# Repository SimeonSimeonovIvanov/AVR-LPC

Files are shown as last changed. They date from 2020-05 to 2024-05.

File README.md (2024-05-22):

# myPLC

Ladder IDE, Win32 API:<br>
https://photos.app.goo.gl/ECsNng8fbLdXbFrD6<br>

**IDE v6**
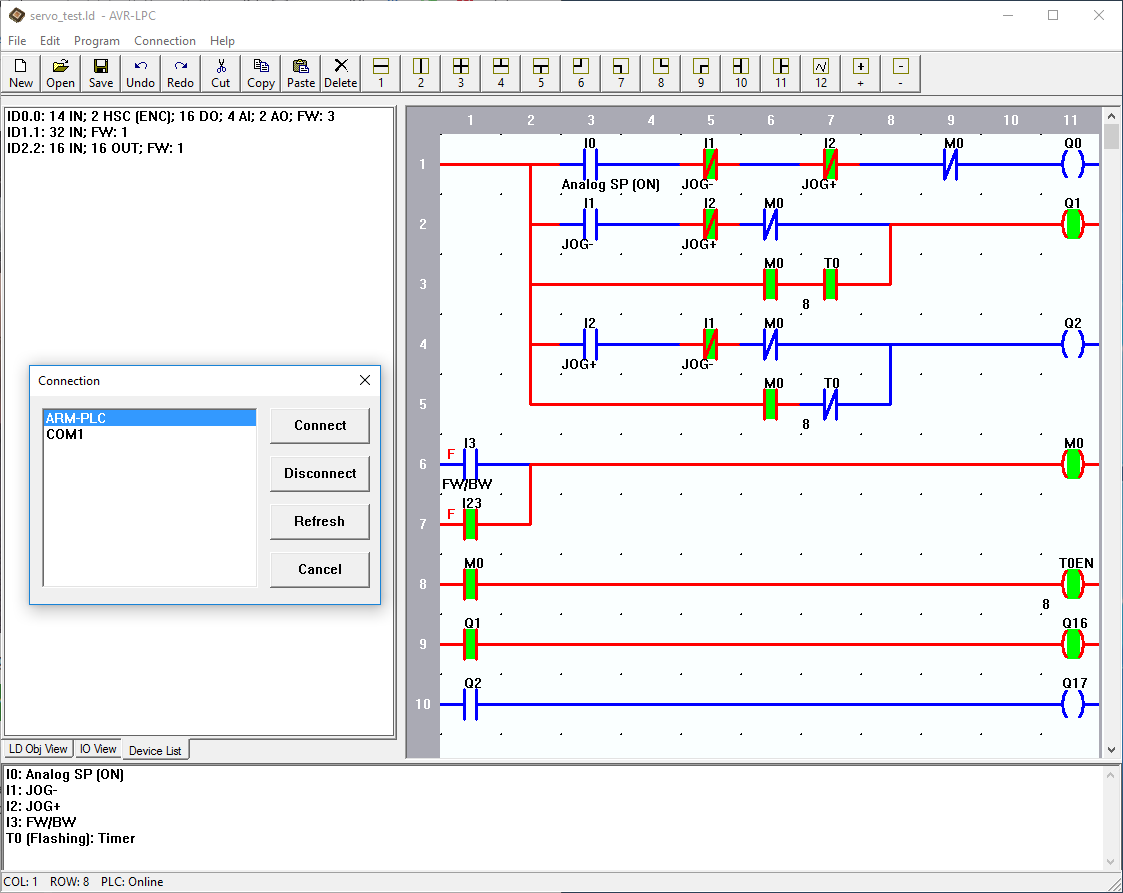
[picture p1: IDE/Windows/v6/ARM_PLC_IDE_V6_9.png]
<br>

**IDE v5**
![Screen Shot](https://lh3.googleusercontent.com/i4vTtbMWcvufEfyPBXmEqtodp0uiaY80SN7nO53SizIuQGnKfskF3hOMWklSdp-E9tZwQFcahZGzqjpb_negQXEel_Ek9y2Q-xKqGe8nZFe8iSiKAYTuJJ7f9EiFlDz4nAf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)<br>

DOS IDE:<br>
<br>

--------------------------------------------------------------------------------------------------------------------------------
**Hardware:**

Electrical Panel: https://photos.app.goo.gl/Vyq1tTFqbRWLNgmy7

1) ARM-PLC v.0.0.0: https://photos.app.goo.gl/mvdGAAyFvAadtSrAA<br>
STM32F446; 14 DI; 1 ENC (2xDI); 16 DO;  4 AI; 2 AO; 1 CAN ( isolated ); 1 RS485 ( isolated ); HMI: LED and SPI expander

![Screen Shot](https://lh3.googleusercontent.com/FQr5hSMQqp2i_nwhZKglB-SCWpj6r-qX7r7Q-jVdQKx1wFxZURQ0LDfvRpwgbzK7AezVR70dovUALOiyYdSaQdRBpPOx6JCb9xz4_ndkZiJmi8XbgmQ-WjyfjlQAHrFRKiS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)

2) v.0.0.9: https://photos.app.goo.gl/yJJbBFp53oGfpSQh1<br>
ATmega128; 16 DI ( isolated ); 16 DO ( isolated ); RS485 ( isolated ); HMI: LED and SPI expander

![Screen Shot](https://lh3.googleusercontent.com/kVyHbxGsG4IzdlXVnGyCS1j1SPNN2gSp2w5qG455mBflZe69VZ90f4dho-pRgDI4RW-WO7sNSD0PA6l9do6jwlTGMlJhjrFqmtGLVl0L7OKdVmlS1hUvMp5UErSR4JhdYPI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)<br>

3) v.0.1.0: https://photos.app.goo.gl/6iC17XjzNHSULanWA<br>
ATmega128; 32 DI ( isolated ); RS485 ( isolated ); HMI: LED and SPI expander

![Screen Shot](https://lh3.googleusercontent.com/OzEl-yrtWVlj1PB5MuoKFS6b4SZ66YS6gCqzX56oWE0lESGWPlYt3V_fz-cltTzUgdABo3lM2OgTONHgAs62rUD7gYELFHMJWC5DPY2WDuDx00NfmaOz2tmeLVn8EhmkOAx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)<br>

4) v.0.0.8 - https://photos.app.goo.gl/Z9C2jXlDd0mY3kmC3 / v.0.0.7 - https://photos.app.goo.gl/mJN1KLpo3TUd7HVa7
ATmega128 + 64KB SRAM; Embedded JTAG ( isolated ); 10 DI ( isolated ); 12 DO ( isolated ); 7 AIN ( 12/16 bits - isolated ); 2 AO ( 16 bits - isolated ); RS485; USB->Virtual Serial Port ( isolated )

![Screen Shot](https://lh3.googleusercontent.com/MFSm0rBE19Bkr6n2bQHMvwQDbrM88FVj6mi0oa1zPS12Zd1XVF8ZQhruDUSjj5ge2i3OTbsoyuJ5pJxQHAq7EGBXzrQ4npnA8TN-FYfQfRKF62vvIBu4lyrC2G8nLSsmaur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)<br>

5) v.0.0.5: https://goo.gl/photos/QCfDXFoU9WnBnyi77
ATxmega128; 10 DI ( isolated ); 12 DO ( isolated ); 7 AI ( not isolated ); 2 AO ( not isolated )

![Screen Shot](https://lh3.googleusercontent.com/CrdKOV2Exipbm48BkSPXY6QQhLZtKpu2Nv74_5UNym-NVNAPvjKg5PgMn0AcWso0ZyiwsN57_bQ84GkdWwb7Ry0Kp0wBErN_FqKzjVGy-RkI7oBeXEOX3lbk3L_sag4jpUt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)<br>

6) v.0.0.3: https://goo.gl/photos/ECHeer7ifiq2STHZ8 - Automatic Fish Feeder With PLC ( old PLC board )
https://www.youtube.com/watch?v=zcFjG9XD-4E&list=PLE616v1yP136VSTElJPbgqLRKw9dhneZ0

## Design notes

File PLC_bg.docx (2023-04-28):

Ladder Editor for ARM PLC v6:

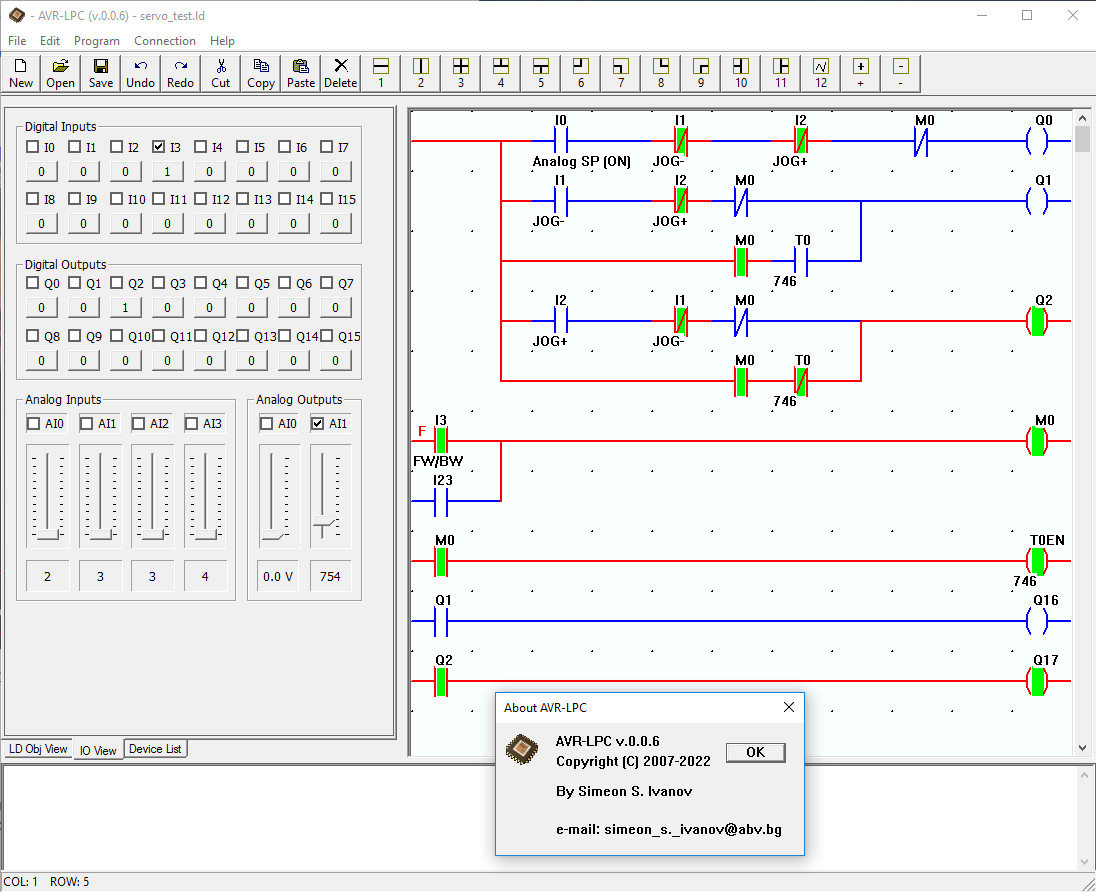
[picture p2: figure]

Ladder Editor for AVR/ARM PLC v5:

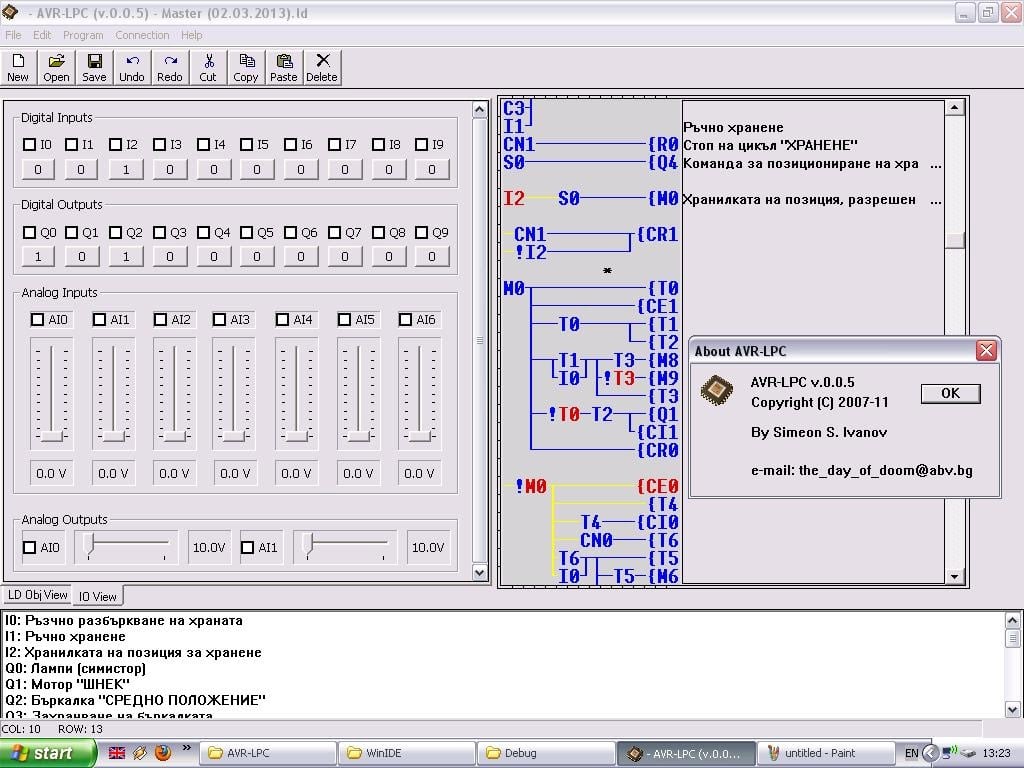
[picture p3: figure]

DOS Version:

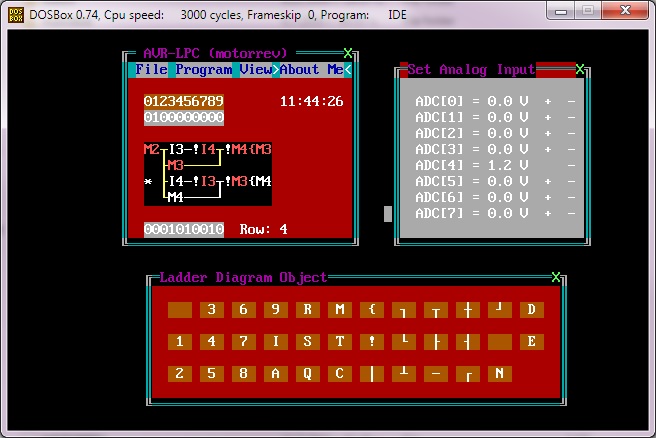
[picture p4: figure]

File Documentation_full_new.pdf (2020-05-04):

# ModBUS âõîäíî-èçõîäåí ìîäóë

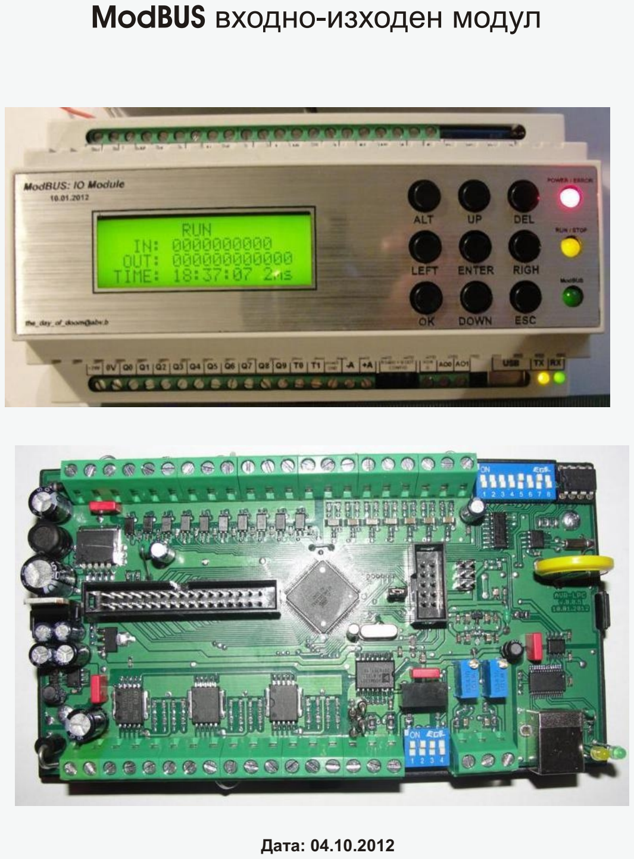
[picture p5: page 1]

## Äàòà: 04.10.2012

### УВОД

Предлаганият | входно/изходен | модул | е | предназначен | за | целите | на
автоматизацията. Управлението му по ModBUS го прави привлекателен за специалистите използващи операторски панели тип PLC, като тяхно входно/изходно разширение. Модулът е базиран на FreeModBUS – open source проект,чийто автор е
Christian Walter MSe. Повече информация може да се намери на www.freemodbus.org.
Приложеното CD съдържа и модифицирания вариант на стека за Atxmega128А1. На него може да бъде видяна и библиотеката на графичния диспплей JM12232

## (SED1520). Източникът и е: http://en.radzio.dxp.pl/sed1520/. Целият останал код, е

авторски и не подлежи на разпространение.

### ОБЩО ОПИСАНИЕ НА МОДУЛА

Модулът е с потребителски интерфейс съставен от LCD дисплей и клавиатура. Кутията е с размери (150x85x85 mm), за монтаж на DIN45 шина.

На фиг.1 е показан общ изглед на модула, разположение на цифровите входове (I0-I9), аналоговите входове (AI0-AI6), цифровите изходи (Q0-Q11), аналоговите изходи (AO0 и AO1), RS485 интерфейса (–A и +A). В Таблица 1 е описано предназначението на ключетата SW1 и SW2, в Таблица 2 – на светодиодите.

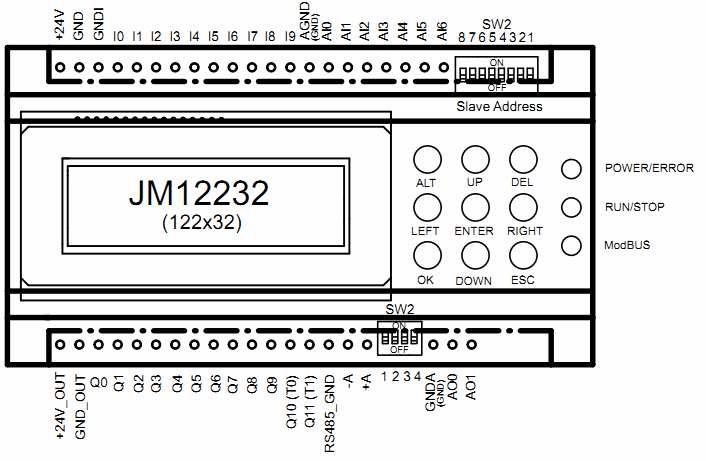
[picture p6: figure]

Таблица 1: Описание на DIP ключетата на модула

Пин | SW1 (номерация отляво надясно в нарастващ ред) | Пин | SW2 (номерация отдясно наляво в нарастващ ред)
1 Включва 120Ω терминиращ | резистор на RS485 интерфейса. | 1 Ако ключе 4 на SW1 e в OFF то след | рестарт SW2 задава адрес на модула в

Фиг.1. Общ изглед на модула

2

3

Включват изтеглящи резистори към RS485 линията.

=//=

4

След рестарт, ако ключето е в OFF не се предприема никакво действие.
В случаите, в които всички ключета на SW2 са в OFF се активира boot loader. Излиза се чрез рестарт или инструкция от програмиращия софтуер.
След излизане от boot loader, при все още активиран ключ BOOT се възстановяват фабричните настройки на модула.

ВАЖНО!!!
Boot loader е опция – в случей че не е добавен, то ключето служи за възстановяване фабричните
настройки на модула.

8

мрежата. Адресът се задава в бинарен вид, като номерата на битовете вървят отдясно-наляво в нарастващ ред.
Ако адресът е невалиден се изписва съответното съобщение, очаквайки въвеждане на коректен адрес и потвърждаване чрез OK. За модулите без UI – чрез рестарт.

Таблица 2: Описание на статусните светодиоди на модула

| СВЕТЕЩ | УГАСНАЛ | МИГАЩ (0.5Hz) | БЪРЗО МИГАЩ
POWER/ERROR | Захранен модул | N/A | Засечена грешка | N/A
RUN/STOP | Модулът е в STOP | N/A | Модулът е в RUN | N/A
ModBUS | N/A | Очакване на пакет | Изтекъл time out на комуникацията, модулът е в “STOP – Time Out” режим | Приемане/Предаване на пакети по ModBUS, модула може да е в RUN или STOP режим.

Комуникацията с PLC се осъществява чрез галванично развързан RS485 интерфейс или виртуален сериен порт, през USB, удобен за връзка с персонален компютър при липса на конвертор за RS485. Разполага с 10 цифрови входа и 12 цифрови изхода (24VDC, оптично развързани. Застъпена е и аналоговата част: 7 входа
и 2 изхода (0-10VDC).

Аналоговите входове позволяват директно прочитане на измерената стойност или преобразуваната в диапазона: от 0 до 100 единици с дискрета 0.1V или от 0 до 1000 съответно през 0.01V. Точността на канал е ±2%.

Аналоговите изходи стандартно се управляват с дискрета от 0.1V (от 0 до 100 единици за 10V обхват). Възможно е дирекно задаване на стойност (0 – 4095) или чрез дискрета от 0.01V. Изборът на работен режим на аналоговата част се осъществява чрез команди по ModBUS. Точността на канал е ±2%.

ТЕХНИЧЕСКИ ХАРАКТЕРИСТИКИ

Параметър | Минимална стойност | Номинална стойност | Максимална стойност | Измервателна единица
Захранване на модула | 18.0 | 24.0 | 36.0 | V, DC
| + | 130.0 | 150.0 | mA
Температура на околната среда | 0.0 | 27.0 | 40.0 | °C
Цифрови входове: 10 опто изолирани | Работно напрежение (абсолютни максимуми) | -40.0 | 0.0 – 24.0 | +40.0 | V, DC
| Логическа ‘1’ | 15.0 | 24.0 | 40.0
| Логическа ‘0’ | -40.0 | 0.0 | 10.0
| Пробивно напрежение между входовете и масата на модула | + | + | 100.0 | V, DC/AC
| Работен ток | 1.0 | 3.0 | 5.0 | mA
| Време за реакция | Основно се определя се от комуникацията по ModBUS | | | ms.
| | + | 50.0 | +
Цифрови Изходи: 12 опто изолирани | Захранване | 20.0 | 24.0 | 36.0 | V, DC
| Пробивно напрежение между изходите и масата на модула | + | + | 100.0 | V, DC/AC
| Изходен ток на канал, защита от късо на изхода. | + | 500.0 | Термична защита при късо на изхода | mA
| Сумарен ток на всички канали | + | + | 6.0А | A
| Време за реакция | Основно се определя се от комуникацията по ModBUS | | | ms.
| | + | 100.0 | +
Аналогови входове: 7 без изолация | Входно напрежение | -30.0 | 0.0 ÷ 10.0 | +30.0 | V, DC
| Входно съпроти-вление на канал | Входното съпротивление се определя от операционен усилвател свързан като повторител, по желание на потребителя на платката може да се добави паралелен входен резистор със стойност от 10kΩ за измерване на напрежение или нискоомен 400Ω (2x200Ω; R0805) за преобразуване на входен ток до 25 mA в номиналното напрежение на входа. Ако се ползва стандартния високоомен вход, при липса на сигнал, модулът ще отчете входно напрежение около 11V (напрежението на насищане на ОУ).

| | >> 100.0 -- | kΩ
Отклонение от измерваната стойност | + | ±10.0 | ±20.0 | mV
Резолюция – за максимална точност се препоръчва директен достъп до регистрите и последващо преобразува не. | 0.1 0.1 | | 0.01 или директен прочит на работните им регистри | V, DC
Време за реакция | Основно се определя се от комуникацията по ModBUS | | | ms.
| + | 100.0 | +
| Изходно напрежение, липсва защита от обратно напрежение | ~0.005 | 0.005 ÷ 10.0 | ~10.70 | V, DC
| Грешка от отместване | ±5.0 | ±10.0 | ±20.0 | mV
| Резолюция | 0.1 | 0.1 | 0.01 или директен запис на работните им регистри | V, DC
| Изходен ток, защитиа от късо | + | 10.0 | ~40.0 | mA
| Време за реакция | Определя се от комуникацията по ModBUS | | | ms.
| | + | 100.0 | +

Аналогови
изходи:

### 2 без

изолация

### ВНИМАНИЕ!!!

1) Параметрите на модула са ориентировачни. Всички са свалени при стайна температура.
2) За калибриране на аналоговите входове и изходи е ползван мултицет MASTECH
MS8218.

### НАСТРОЙКА НА МОДУЛА ЧРЕЗ ПОТРБИТЕЛСКИЯ ИНТЕРФЕЙС (UI)

В нормален работен режим се извежда статус дисплей. На него се изобразява състоянието на модула (спрян/пуснат), грешки, входовете и изходите. Чрез еднократно натискане на ALT могат да се видят измерените стойности на аналоговите входове. При повторно натискане се показват и зададените стойности на аналоговите изходи. Аналоговите изходи се изобразяват в текущия диапазон: 0.0-10.0V; 0.01-10.00V или директно стойността записана в работните регистри. Натискането на ESC ни връща в статусния прозорец.

Навигацията и задаването на параметри се осъществява чрез бутоните на клавиатурата:
UP/ DOWN – Преместване на курсора, задаване на нова стойност на параметър LEFT/ RIGHT – Преместване на курсора, задаване на нова стойност на параметър ENTER – Влизане в подменю
ESC – Връщане стъпка назад, без промяна на последното задание
OK – Избор на текуща стйност на параметър.

Статус дисплей->OK->Главно меню->ENTER->Status:
ОК->Run – Привежда изходите (цифрови и аналогови) в работно състояние ОК->Stop - Привежда изходите (цифрови и аналогови) в не работно състояние (стойности 0)
ESK – връщане в главното меню, без промяна на последното задание

## Статус дисплей->OK->Главно меню->Time Config->ENTER:

ALT / LEFT – задават се часовете
UP / ENTER – задават се минутите
DEL / RIGHT – задават се секундите
OK – възприемане на новите настройки
ESK – връщане в главното меню, без промяна на последното задание

## Статус дисплей->OK->Главно меню->ModBUS Config->ENTER:

BAUD Rate->ENTER: Избор между няколко скорости на комуникацията
(OK – Потвърждаване; ESC – меню назад)
Select Port->ENTER: Избор между RS485 или виртуален сериен порт през USB
(OK – Потвърждаване; ESC – меню назад)
Time Out->ENTER: Колко време след спиране на комуникацията контролерът преминава в стоп режим по изтекло време. Повторното стартиране на контролера е възможно едва когато се възтанови комуникацията чрез команда от UI или през
ModBUS.

### ОПИСАНИЕ НА КОМУНИКАЦИОНИЯ ПРОТОКОЛ

Комуникацията с модула се извършва чрез ModBUS. При този протокол комуникацията между устройствата е на базата главен-подчинен(и). Главното

(master) устройство представлява PLC или PC, а модула – подчинено (slave). В нормално състояние всички подчинени устройства очакват заявка от главното.
Заявката | съдържа | адреса | на | устройството, команда | за | четене/запис | на
регистър/регистри, самата информация и CRC.

## MODBUS RTU

ВАЖНО!!! – текущата версия на модула поддържа само “Big Endian” формат на данните. Това означава, че старшите битове се изпращат преди младшите.

Физически слой:

Атрибут | Описание
Интерфейс | RS485, Виртуален сериен порт (USB<>COM). Избират се чрез UI на модула или чрез ModBUS запис в регистър.
Информационен формат | ”Big Endian” 1 стоп бит 8 дата бита Контрол по четност (Even Bit) 2 стоп бита
Стандартни скорости | 19200, 38400, 57600 и 115000 bps. Избират се чрез UI на модула или чрез ModBUS запис в регистър (при втория вариант могат да бъдат зададени и други скорости на комуникация).

### ФОРМАТ НА MODBUS RTU ПАКЕТ

Пакетът, изпращан от master към slave и обратно представлява:

## ID_Slave, Function_Code, User_Data, CRC16

ID_Slave – Идентификатор на slave device, цяло число, в диапазона от 1 до 247. Нула е специален адрес: ползва се за едновременно подаване на заявка към всички устройства в мрежата.

Function_Code – Оределя регистровата област върху която ще се чете и/или записва. Пряко е обвързана с формата на User_Data.

User_Data – Информацията която се изпраща към модула. Формата й се определя от Function_Code, в общия случай съдържа стартов адрес и брой регистри. Ако командата е запис се включва и новото съдържание на регистрите.

CRC16 – Чек сума на пакета.

При валидно изпратен и master, slave връща отговор съдържащ номера му, използвания функционален код, потребителската информация (ехо при запис) или евентуален код за грешка.

### КОМАНДИ (ФУНКЦИОНАЛНИ КОДОВЕ) ПОДЪРЖАНИ ОТ МОДУЛА

Функционалните кодове определят контекста и формата на съобщението. Те непосредствено определят върху коя група от регистри се изпълнява текущата команда:

Офицялни Команди подържани от модула

Код | Група | Описание

Регистрите представляват масиви от битове*, байтове или думи разпределени по групи според разрешените действия върху тях (четене и/или запис).

Битовите регистри на модула са пряко обвързани с входовете и изходите му включително и някои вътрешни състояния. Те реално са логическа структура. Достъпът до тях се осъществява чрез командите за работа с байтови регистри, съставени от желаните битове.

### ЧЕТЕНЕ НА ДИСКРЕТНИ ВХОДОВЕ (FC2)

Заявка от Master:

Байт | Описание
0 | Адрес на подчиненото устройство (1 – 247), 0 е за адресиране на всички устройства
1 | Функционален код 0x02
2 | Адрес на първия бит (MSB)
3 | Адрес на първия бит (LSB)
4 | Брой на битовете за четене (MSB)
5 | Брой на битовете за четене (LSB)
6 | CRC16 LSB
7 | CRC16 MSB

Отговор от Slave:

Байт | Описание
0 | Адрес на отговарящото подчинено устройство
1 | Функционален код 0x02
2 | Брой върнати байтове
3 | Байт 0
N | Байт N
3 + Брой баитове | CRC16 LSB
4 + Брой байтове | CRC16 MSB

Примерна команда за прочитане на 16-те бита:

## 10, 2, 0, 0, 0, 16, CRC[120,189] Device ID: 10

FC: 2

## Start Address: 0 Bits count: 16 (2 Byte)

Разпределението на битовете във върнатите байтове е: BYTE[0] - Цифрови входове:

(FC)
2 Еднобайтови регистри само за четене | (разделени логически на отделни битове). | Четене на дискретни входове
1 Четене на дискретни изходи 5 Запис на един дискретен изход | Еднобайтови регистри за четене/запис: Coils (разделени логически на отделни битове).
15 | | Запис на няколко дискретни изхода

4 16 битови регистри само за четене
3 Четене на 16 битови регистри 6 Запис на 16 битов регистър | 16 битови регистри за четене/запис.
16 | Запис на 16 битови регистри

## BIT[0:7] - Входове [I0:I7]

BYTE[1] - Цифрови входове:

## BIT[0:1] - Входове [I8:I9]

BIT 2 - Защита на изходите (1 – Задействана защита)

BIT[3:7] – Не се ползват

ЧЕТЕНЕ НА ДИСКРЕТНИ ИЗХОДИ (FC1)

Заявка от Master:

Байт | Описание
0 | Адрес на подчиненото устройство (1 – 247), 0 е за адресиране на всички устройства
1 | Функционален код 0x01
2 | Адрес на първия бит (MSB)
3 | Адрес на първия бит (LSB)
4 | Брой на битовете за четене (MSB)
5 | Брой на битовете за четене (LSB)
6 | CRC16 LSB
7 | CRC16 MSB

Отговор от Slave:

Байт | Описание
0 | Адрес на отговарящото подчинено устройство
1 | Функционален код 0x01
2 | Брой върнати байтове N
3 | Байт 0
N Байт N
3 + N | CRC16 LSB
4 + N | CRC16 MSB

Примерна команда за прочитане на 16-те бита:

## 10, 1, 0, 0, 0, 16, CRC[60,189] Device ID: 10

FC: 1

## Start Address: 0 Bits count: 16 (2 Byte)

Разпределението на битовете във върнатите байтове е:

BYTE[0] - Цифрови изходи:

## BIT[0:7] - Изходи [Q0:Q7]

BYTE[1] - Цифрови изходи:

## BIT[0:1] - Изходи [Q8:Q9] BIT[2:3] – Изходи [Q10:Q11] <=>[T0:T1]

BIT[4:7] – Не се ползват

### ЗАПИС НА ДИСКРЕТЕН ИЗХОД (FC5)

Заявка от Master:

Байт Описание

0 | Адрес на подчиненото устройство (1 – 247), 0 е за адресиране на всички устройства
1 | Функционален код 0x05
2 | Адрес на изходния бит (MSB)
3 | Адрес на изходния бит (LSB)
4 | Стойност на Бита(Изхода): 0xff – Битът се вдига в единица; 0x00 – Битът се смъква в нула
5 | 0x00
6 | CRC16 LSB
7 | CRC16 MSB

Отговор от Slave:

Байт | Описание
0 | Адрес на отговарящото подчинено устройство
1 | Функционален код 0x05
2 | Адрес на изходния бит (MSB)
3 | Адрес на изходния бит (LSB)
4 | Стойност на Бита(Изхода): 0xff – Битът e единица; 0x00 – Битът e нула
5 | 0x00
6 | CRC16 LSB
7 | CRC16 MSB

Примерна команда за запис на единица в нулевия изход (Q0):

## 10, 5, 0, 0, 255, 0, CRC[141,65] Device ID: 10

FC: 5

## Start Address: 0 Coil (Q0) state: 1 (0xff)

### ЗАПИС НА ДИСКРЕТНИ ИЗХОДИ (FC15)

Заявка от Master:

Байт | Описание
0 | Адрес на подчиненото устройство (1 – 247), 0 е за адресиране на всички устройства
1 | Функционален код 0x015
2 | Адрес на изходния бит (MSB)
3 | Адрес на изходния бит (LSB)
4 | Брой битове (MSB)
5 | Брой битове (LSB)
6 | Брой байтове N
N + 6 | Битова маска 0
N + 7 | Битова маска N
N + 8 | 0x00
N + 9 | CRC16 LSB
N + 10 | CRC16 MSB

Отговор от Slave:

Байт | Описание
0 | Адрес на отговарящото подчинено устройство
1 | Функционален код 0x015
2 | Адрес на изходния бит (MSB)
3 | Адрес на изходния бит (LSB)
4 | Брой битове (MSB)
5 | Брой битове (LSB)

5 + Брой баитове | CRC16 LSB
6 + Брой байтове | CRC16 MSB

Примерна команда за запис на единици на първите осем изхода (Q0 – Q7):

## 10, 15, 0, 0, 0, 8, 1, 255, CRC[255, 102] Device ID: 10

FC: 15

## Start Address: 0 Coil Count: 8 Byte Count: 1 Coil Mask: 255 (0xff)

### ЧЕТЕНЕ НА 16 БИТОВИ ВХОДНИ РЕГИСТРИ (FC4)

Заявка от Master:

Байт | Описание
0 | Адрес на подчиненото устройство (1 – 247), 0 е за адресиране на всички устройства
1 | Функционален код 0x04
2 | Адрес на първия регистър (MSB)
3 | Адрес на първия регистър (LSB)
4 | Брой регистри за четене (MSB)
5 | Брой регистри за четене (LSB)
6 | CRC16 LSB
7 | CRC16 MSB

Отговор от Slave:

Байт | Описание
0 | Адрес на отговарящото подчинено устройство
1 | Функционален код 0x04
2 | Брой върнати байтове N (2 x Брой регистри за четене)
3 | WORD[0] (MSB)
4 | WORD[0] (LSB)
N + 1 | WORD[N-1] (MSB)
N + 2 | WORD[N-1] (LSB)
3 + Брой баитове | CRC16 LSB
4 + Брой байтове | CRC16 MSB

Примерна команда за директно прочитане на 7-те аналогови входа без корекция:

## 10, 4, 0, 0, 0, 7, CRC[176, 179] Device ID: 10

FC: 4

## Start Address: 0 Word count: 7 (14 Byte)

Разпределението на регистрите във върнатите байтове е: WORD_0[BYTE_0:BYTE_1] – Аналогов вход 0, директен прочит

WORD_1[BYTE_2:BYTE_3] – Аналогов вход 1, директен прочит
=//=

## WORD_6[BYTE_12:BYTE_13] – Аналогов вход 6, директен прочит

### ЧЕТЕНЕ НА 16 БИТОВИ ВХОДНО/ИЗХОДЕНИ РЕГИСТРИ (FC3)

Заявка от Master:

Байт | Описание
0 | Адрес на подчиненото устройство (1 – 247), 0 е за адресиране на всички устройства
1 | Функционален код 0x03
2 | Адрес на първия регистър (MSB)
3 | Адрес на първия регистър (LSB)
4 | Брой регистри за четене N (MSB)
5 | Брой регистри за четене N (LSB)
6 | CRC16 LSB
7 | CRC16 MSB

Отговор от Slave:

Байт | Описание
0 | Адрес на отговарящото подчинено устройство
1 | Функционален код 0x03
2 | Брой върнати регистри N
3 | WORD[0] (MSB)
4 | WORD[0] (LSB)
N + 1 | WORD[N-1] (MSB)
N + 2 | WORD[N-1] (LSB)
3 + Брой баитове | CRC16 LSB
4 + Брой байтове | CRC16 MSB

Примерна команда за прочитане на коригиращите константи на 7-те аналогови входа:

## 10,3,0,5,0,7, CRC[21,114] Device ID: 10

FC: 3

## Start Address: 5 Word count: 7 (14 Byte)

Разпределението на регистрите във върнатите байтове е: WORD_5[BYTE_10:BYTE_11] – Калибрираща константа на Аналогов вход 0

WORD_6[BYTE_12:BYTE_13] – Калибрираща константа на Аналогов вход 1
=//=
WORD_11[BYTE_22:BYTE_23] – Калибрираща константа на Аналогов вход 6

### ЗАПИС НА 16 БИТОВ ВХОДНО / ИЗХОДЕН РЕГИСТЪР (FC6)

Заявка от Master:

Байт | Описание
0 | Адрес на подчиненото устройство (1 – 247), 0 е за адресиране на всички устройства
1 | Функционален код 0x06
2 | Адрес на регистъра (MSB)
3 | Адрес на регистъра (LSB)

4 | Нова стойност на регистъра: WORD[0] (MSB)
5 | Нова стойност на регистъра: WORD[0] (LSB)
6 | CRC16 LSB
7 | CRC16 MSB

Отговор от Slave:

Байт | Описание
0 | Адрес на отговарящото подчинено устройство
1 | Функционален код 0x06
2 | Адрес на регистъра (MSB)
3 | Адрес на регистъра (LSB)
4 | Върната информация: WORD[0] (MSB)
5 | Върната информация: WORD[0] (LSB)
6 | CRC16 LSB
7 | CRC16 MSB
Примерна команда за запис на RUN в статусната дума на модула и изчистване на последно възникналите грешки:

## 10,6,0,15, OLD_STATUS>>8, ~0x03 & OLD_STATUS, CRC Device ID: 10

FC: 6

## Start Address: 15

ЗАПИС НА 16 БИТОВИ ВХОДНО / ИЗХОДНИ РЕГИСТРИ (FC16)

Заявка от Master:

Байт | Описание
0 | Адрес на подчиненото устройство (1 – 247), 0 е за адресиране на всички устройства
1 | Функционален код 0x10
2 | Адрес на първия регистър (MSB)
3 | Адрес на първия регистър (LSB)
4 | Брой 16-битови регистри за запис N (MSB)
5 | Брой 16-битови регистри за запис N (LSB)
6 | Брой 8-битови регистри за запис (2 * N)
7 | WORD[0] (MSB)
8 | WORD[0] (LSB)
N + 7 | WORD[N-1] (MSB)
N + 8 | WORD[N-1] (LSB)
6 | CRC16 LSB
7 | CRC16 MSB

Отговор от Slave:

Байт | Описание
0 | Адрес на отговарящото подчинено устройство
1 | Функционален код 0x10
2 | Брой върнати регистри N
3 | WORD[0] (MSB)
4 | WORD[0] (LSB)
N + 1 | WORD[N-1] (MSB)
N + 2 | WORD[N-1] (LSB)
3 + Брой баитове | CRC16 LSB
4 + Брой байтове | CRC16 MSB

Примерна команда за нулиране на калибриращите константи на аналоговите изходи (не се препоръчва ако не се познава достатъчно добре модулът и начините за възстановяване на константите му по ModBUS):

## 10, 16, 0, 12, 0, 2, 4, 0, 0, 0, 0,CRC[214,222] Device ID: 10

FC: 16

## Start Address: 5 Word count: 2 (4 Byte)

### РЕГИСТРОВА КАРТА НА МОДУЛА

Регистри за четене / запис (8-битови организирани в 16 адресируеми бита), FC1,

## FC5 и FC15:

Байт, Начален адрес | Бит | Предназначение | Стойност
1 | 0
0 | 0 Цифров изход Q0 | | Задействан | Не задействан
| =//= | =//=
| 7 Цифров изход Q7
1 | 0 Цифров изход Q8
| =//= | =//=
| 7 Цифров изход Q15
2 | 0 Цифров изход Q16
| =//= | =//=
| 7 Цифров изход Q23

Регистри само за четене (16-битови), FC4:

WORD начален адрес | Байт | Предназначение | Стойност ,
MSB | LSB | | Минимална | Максимална
0 | 1 | 0 | Аналогов вход AI0, стойност прочетена от ADC-то | 0 | Определя се от константата на аналоговия вход
=//= | =//= | =//= | =//=
6 | 13 | 12 | Аналогов вход AI6, стойност прочетена от ADC-то
7 | 15 | 14 | Аналогов вход AI0, скалирана стойност | 0 | 1000

Регистри само за четене (8-битови организирани в 16 адресируеми бита), FC2:
Байт, начален адрес | Бит | Предназначение | Стойност
1 | 0
0 | 0 Цифров вход I0 | | Задействан | Не задействан
| =//= | =//=
| 7 Цифров вход I7
1 | 0 Цифров вход I8
| =//= | =//=
| 7 Цифров вход I15
2 | 0 Цифров вход I16
| =//= | =//=
| 7 Цифров вход I23
3 | 0 Термична защита на изходите
| =//= | N/A
| 7 N/A

=//= | =//= | =//= | =//= | Отговаря на 0.00 V | Отговаря на 10.00 V
13 | 27 | 26 | Аналогов вход AI6, скалирана стойност
14 | 29 | 28 | Аналогов вход AI1 | Аналогов вход AI0 | 0 Отговаря на 0.0 V | 100 Отговаря на 10.0 V
15 | 31 | 30 | Аналогов вход AI3 | Аналогов вход AI2
14 | 33 | 32 | Аналогов вход AI5 | Аналогов вход AI4
16 | 35 | 34 | N/A | Аналогов вход AI6

Регистри за четене и запис (16-битови), FC3, FC6 и FC16:

WORD начален адрес | Байт | Предназначение | Стойност ,
MSB | LSB | | Минимална | Максимална
0 | 1 | 0 | Аналогов изход AO0, стойност без корекция | 0 | Определя се на базата константата на аналоговия изход
1 | 3 | 2 | Аналогов изход AO1, стойност без корекция
2 | 5 | 4 | Аналогов изход AO0, скалирана стойност | 0 Отговаря на 0.00 V | 1000 Отговаря на 10.00 V
3 | 7 | 6 | Аналогов изход AO1, скалирана стойност
4 | 9 | 8 | Аналогов изход AO1 | Аналогов изход AO0 | 0 Отговаря на 0.0 V | 100 Отговаря на 10.0 V
5 | 11 | 10 | Калибрираща константа на аналогов вход AI0 | | 0 | 20470 (стойност на аналоговия вход умножена по десет, при 10.00V задание)
=//= | =//= | =//= | =//=
11 | 23 | 22 | Калибрираща константа на аналогов вход AI6
12 | 25 | 24 | Калибрираща константа на аналогов изход AO0
13 | 27 | 26 | Калибрираща константа на аналогов изход AO1
| Байт | Бит | Стойност | Значение
| 28 LSB, Аналогови входове | [0..1] | 0 Без промяна на предишното състояние
| | | 1 Пълен диапазон: 0 ÷ 2047 – НЕ СЕ ПОЛЗВА!
| | | 2 Диапазон: 0 ÷ 1000 (0.00 V - 10.00 V) – НЕ СЕ | ПОЛЗВА!
| | | 3 Диапазон: 0 – 100 (0.0 V - 10.0 V) – НЕ СЕ ПОЛЗВА!
| | 2 | 1/0 | N/A
| | 3 | 1/0 | N/A
| | 4 | 1/0 | N/A
| | 5 Зареждане на фабричните калибриращи константи | 1 - Старт 0 – Край (Статус)

### 6 Зареждане на калибриращите константи от

### EEPROM

7 | | Зареждане на калибриращите константи в EEPROM
29 MSB, Аналогови изходи | DAC0 [0..1] и DAC1 [2..3] | 0 Без промяна на предишното състояние
1 Пълен диапазон: 0 ÷ 4095 | | Сменя работния диапазон и формата на изобразяваната информация на екрана на DAC.

### 2 Диапазон: 0 ÷ 1000 (0.00 V - 10.00 V)

3 | Диапазон: 0 – 100 (0.0 V - 10.0 V)
4 | 1/0 | Зареждане на работния диапазон в EEPROM
5 | 1 - Старт | Зареждане на фабричните калибриращи константи

14

| | 6 Зареждане на калибриращите константи от | 0 - Край | EEPROM
| | 7 | | Зареждане на калибриращите константи в EEPROM
| 30 LSB, статусни битове, последна грешка | 0 1 – Run | 0 – Stop | Run разрешава извеждането на стойности на цифровите и аналоговите изходи Stop режим привежда изходите в неутрално състояние нула.
| | 1 Термична защита, изчиства се ръчно.
| | 2 1/0 | | Задействана защита (1) по time out на комуникацията. Модулът автоматично минава в stop режим от който се излиза след подаване на команда RUN (ръчно или по ModBUS), при което бита се изчиства до следващия time out.
| | 4 | 1/0 | N/A
| | 5 | 1/0 | N/A
| | 6 | 1/0 | N/A
| | 7 | 1/0 | N/A
| 31 MSB, статусни битове, последна грешка | 0 | 1/0 | N/A
| | 1 | 1/0 | N/A
| | 2 | 1/0 | N/A
| | 3 | 1/0 | N/A
| | 4 | 1/0 | N/A
| | 5 | 1/0 | N/A
| | 6 | 1/0 | N/A
| | 7 | 1/0 | N/A
WORD, начален адрес | Байт | Предназначение | Стойност
MSB | LSB | | Минимална | Максимална
16 | 33 | 32 | BAUD Rate / 10 | 9600/10 bps. | 115000/10 bps.
17 | Байт | Бит | Стойност | Значение
| 34 LSB, Сериен порт, контролен регистър | | 0 Без промяна на предишното състояние
| | | 1 Even

15

### 2 Odd [0..1] 3 None

[2..3] | 0 Без промяна на предишното състояние
| 4 | RS485
| 8 FT232 (USB Serial)
6 | 1/0 | N/A
7 | 1/0 | N/A
35 LSB, Сериен порт, контролен регистър | 0 | 1/0 | N/A
| 1 | 1/0 | N/A
| 2 | 1/0 | N/A
| 3 | 1/0 | N/A
| 4 | 1 | Зареждане на новите настройки
| 5 | 1 | Зареждане на фабричните настройки
| 6 | 1 | Зареждане на настройките от EEPROM
| 7 | 1 | Зареждане на настройките в EEPROM
WORD, начален адрес | Байт | Предназначение | Стойност
MSB | LSB | | Минимална | Максимална
18 | 37 | 36 | ModBUS Time out – Време на изчакване след прекъсване на комуникацията, изтече ли контролера минава в стоп режим по time out. | 100 ms или 0 – Забранява time out | 10,000 ms.

### ОСОБЕНОСТИ ПРИ ПОЛЗВАНЕ НА АНАЛОГОВИТЕ ВХОДОВЕ

При директно четене на измерената стойност от аналогов вход, напрежението се определя по формулата:

,[0.00..10.10] 100 ][,

N,CONST

N | N
AI

## AI V = AI ×

### Където:

AIN,CONST е цяло число, със стойност от 10000 до 20470. Средно варира около 18000 (1.8V). Физически се определя от резисторен делител, смъкващ напрежението до 2.048V (максимално). Константите на входовете могат да се променят, зареждат, записват в /от EEPROM или да се възстановят заводските им стойности.

### ОСОБЕНОСТИ ПРИ ПОЛЗВАНЕ НА АНАЛОГОВИТЕ ИЗХОДИ

За да се определи константата, трябва аналоговият изход да е в режим директно извеждане на стойност. В този случай се зарежда максималната му стойност 4095. Измерва се полученото напрежение и се пресмята по формулата:

_ | [, ]
4095 100 ( | ), | Измерено Напрежение V
A | CONST N
OUT | = | ×

Полученото цяло число е в диапазона от 30000 до 40950. Физически се определя от коефицента на усилване и изходния диференциален усилвател.

Константите на изходите могат да се променят, зареждат, записват в / от EEPROM или да се възстановят заводските им стойности.

### НАСТРОЙКИ НА КОМУНИКАЦИЯТА ПО MODBUS

Командата за потвърждаване на новите настройки на серийния порт трябва да се извършва не по-често от 500 mS, в противен случай е възможно ModBUS стека да блокира.

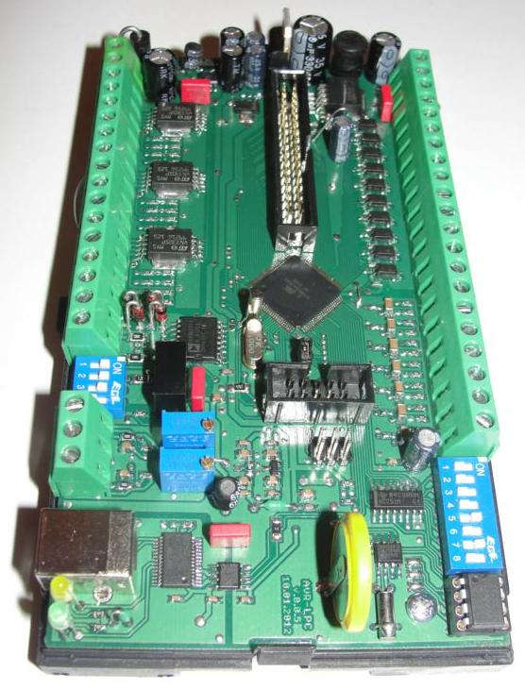
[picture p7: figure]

## ModBUS входно-изходен модул

## Board and Software: v.0.0.5

## (работна документация)

***
***
***

## Дата: 04.10.2012

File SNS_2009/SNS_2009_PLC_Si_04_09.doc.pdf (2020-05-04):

РУСЕНСКИ УНИВЕРСИТЕТ | СТУДЕНТСКА НАУЧНА СЕСИЯ – СНС’09

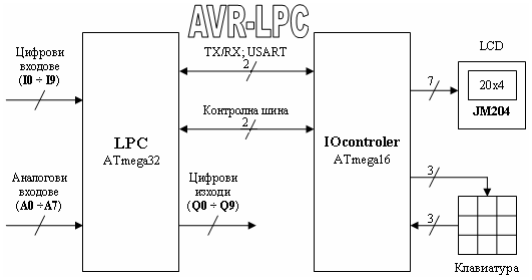
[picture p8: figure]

Програмируем контролер AVR–LPC

автор: Симеон Иванов
научен ръководител: гл. ас. д-р инж. Анелия Манукова

Целта на статията е да представи проект “AVR-PLC”, изграждащ PLC контролер и включващ крайно устройство с интегриран потребителски интерфейс (UI) и ядро (kernel), грижещо се за изпълнение на ladder diagram. Представена е развойна среда, ускоряваща процеса на разработване и тестване на потребителските програми.
Ключови думи: PLC, ladder diagrams, IDE, x86, DOS

ВЪВЕДЕНИЕ
При съвременното развитие на електронните устройства за управление на технологични обекти и процеси широко приложение намират програмируемите логически контролери (PLC). Тяхна основна цел е изместването на управляващите устройства, изградени на релейно-контакторна база. За разлика от хардуерните решения, при които логиката е „твърдо” зададена, при PLC е софтуерно (програмно), позволявайки гъвкавост при изготвянето и настройването на системата. Съществуват множество езици и методи за програмиране, като в настоящия проект са избрани ladder diagrams (стълбични диаграми), които се явяват пряк заместител на релейно-контакторна схемотехника.

ИЗГРАЖДАНЕ НА ПРОГРАМИРУЕМ ЛОГИЧЕСКИ КОНТРОЛЕР AVR–LPC Структурната схема на AVR–LPC е показана на фиг.1. За реализацията му са използвани микроконтролери на фирмата ATMEL. Представяният PLC контролер е изграден на базата на два осем битови микроконтролера: ATmega32 с 32 КBytes Flash и ATmega16 с 16 КBytes Flash. ATmega32 изпълнява основната част от софтуера: ядрото (kernel), грижещо се за изпълнението на диаграмата, потребителския интерфейс (UI), системния часовник и всички софтуерни обекти (часовници, таймери, броячи и др.). Вторият контролер е входно - изходен (IOcontroler), като за неговата реализация е ползван ATmega16. Обслужва управлението на дисплея (JM204; буквено – цифров; 20х4 символа) и клавиатура (9 бутона). Комуникацията между двата контолера е двупосочна, чрез сериен интерфейс, като допълнително е добавена контролна шина.

Фиг.1. Структурна схема на AVR–LPC.

Алгоритъмът на работа на главния контролер AVR–LPC е показан на фиг.2. Блок „Началното установяване” инициализира системните променливи, IOcontroler, зареждане на ladder diagram и настройките от EEPROM, както и стартиране на системата. Следва оперативният цикъл. Той обработва потребителския интерфейс UI, четат се цифровите входове, изпълнява се потребителската програма и получения резултат се записва на цифровите изходи. Частта от алгоритъма, свързана с пунктир на фиг.2., обработва прекъсванията. От нея ясно се вижда, че системния часовник е с най-висок приоритет, грижейки се за обновяването на часа и обектите на ladder diagram: таймери и часовници. Заявката за прекъсването на ADC прочита и филтрира измерената стойност на аналоговия входа на контролера.

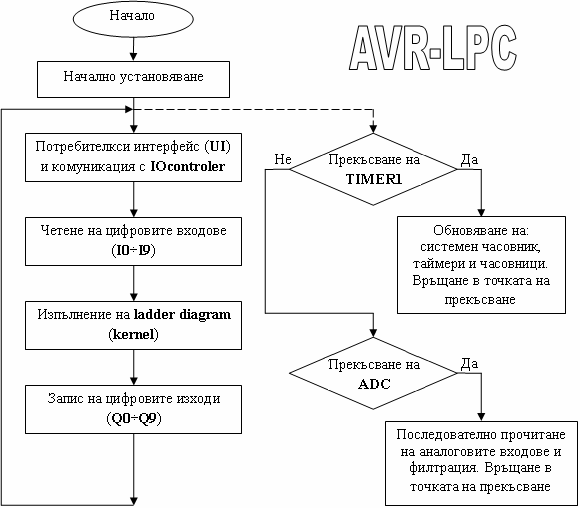
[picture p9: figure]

На фиг.3. е показан алгоритъмът на работа на входно – изходния контролер (IOcontroler). От контекста на фиг.2. се вижда, че LPC контролера е главен, a IOcontroler е подчинен. След началното установяване, следва цикъл на командите. В зависимост от типа на командата, последната се подава на драйвера на дисплея или клавиатурата.
Подсистемата | на | клавиатурата | използва | двупосочната | връзка | между
контролерите (за разлика от тази на дисплея, чакаща заявки за изпълнение). При подаване на команда за прочитане на последния избран бутон, IOcontroler връща ASCII кода му съхранен в буфер. Драйверът на клавиатурата използва заявките за прекъсване, за сканиране и засичане на натиснат бутон.

Фиг.2. Блок-схема на алгоритъма на работа на главния контролер AVR–LPC.

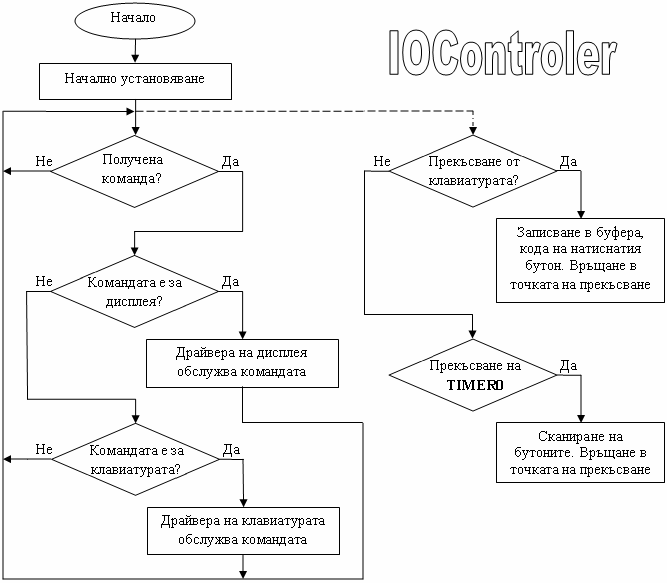
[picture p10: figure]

РЕЗУЛТАТИ
Техническите параметри на изградения AVR-LPC са представени в табл.1. Разделението на хардуерни и софтуерни параметри е наложено от структурата на крайното устройство. Хардуерните описват контролера като черна кутия с n входа и m изхода. Софтуерните показват вътрешната и структура – дават ясна представа за възможностите й. Описаните софтуерни обекти са реализирани по 10 броя.
В табл.1 е зададено „гарантирано време за реакция” като продължителността на оперативния цикъл варира в зависимост от големината и сложността на въведената програма. Измерването му е извършено при размер на диаграмата от 16x12 символа.
При проведените тестове за максимален размер 16х30 символа, ограничен от наличната памет на контролера, се отчете минимален период на оперативния цикъл от порядъка на 25ms. Следователно „гарантираното време за реакция” нараства на 50ms, при запазена резолюция на таймерите и броячите от 1ms. Отчитайки факта, че контролерът е предназначен за управление на инертни процеси, може да се направи извода, че постигнатите резултати във времето са добри.
Въпреки, че спада към micro PLC, от софтуерна гледна точка, ядрото може да подържа до 256 входно – изходни точки и обекта на ladder diagram. Ограниченията произтичат от страна на хардуера.

Фиг.3. Блок-схема на алгоритъма на работа на входно - изходния контролер на
AVR–LPC (IOcontroler).

Таблица.1. Технически параметри на програмируемия контролер AVR–LPC

Успоредно с контролера е разработена развойна среда (IDE), работеща под управлението на операционните системи DOS, Windows 98, Windows NT или Linux (с подходящ емулатор: DOSBox или Wine), като на ниво ядро те са напълно съвместими. DOS приложението е с меню прозоречен интерфейс.
Диалоговият прозорец на DOS средата е показан на фиг.4. Виждат се: зареден фрагмент от суматор, прозорци за редактиране на аналогов компаратор, брояч и диалог за запазване на файл. Главния прозорец, съдържа индикация за състоянието на входовете и изходите, бутони за задаване на стойността на цифровия вход.

Хардуерни параметри
цифрови входове (I0÷I9) | - минимално време за реакция: 10ms; - гарантирано време за реакция: >20ms;
цифрови изходи (Q0÷Q9) | - минимално време за реакция: 10ms; - гарантирано време за реакция: >20ms;
аналогови входове (A0÷A7; мултиплицирани) | - 10-bit ADC; - честота на дискретизация: 125KHz; - софтуерен филтър;

Софтуерни параметри
ladder diagram: 16x12 символа | - произволен формат на запис; - автоматично разпознаване на въвеждания обект;
часовници | - 24 часов период; - час на включване/ изключване;
таймери | - минимален период: 10ms; - гарантиран период: >20ms; - максиален период: 65,535s; - три режима на работа: мултивибратор, таймер със закъснение на включването (ON delay timer), таймер със закъснение на изключването (OFF delay timer);
аналогови компаратори | - софтуерно избиране стойността на опорно напрежение; - тип на сравнение: <; =; >; - избор на аналогов вход;
броячи | - избор посоката на броене (чрез контактна инструкция) - типа на сравнение: <; =; >; - максимална стойност: 65535; - възможност за автоматично нулиране на брояча; - минимално време за реакция: 10ms.; - гарантиранo време за реакция: >20ms;

маркери
RS тригери

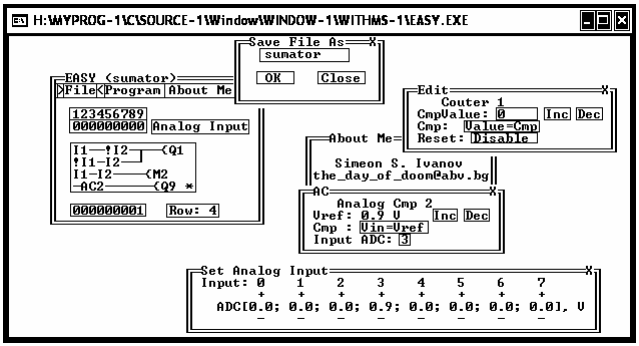
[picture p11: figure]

ЗАКЛЮЧЕНИЕ
Разработен е програмируем логически контролер.AVR-LPC, изпълняващ ladder diagram, и съпъстващатата го развойна среда. При наличие на подходящ хардуер пригоден за работа в промишлени условия (компютър базиран на х86 процесор, например PC/104), приложението може да се ползва директно, спестявайки разработването на специализиран хардуер. Ползването на х86 система, ще осигори по-голям обем и скорост на изпълнение на ladder diagram. В DOS среда, потребителя разполага с файлова система, позволяваща съхраненение, зареждане, изпълнение на произволна програма. Това определя и по-високата продуктивност на предложената система.
Проведените тестове на прототипа и развойната среда на контролера доказват работоспособността му и определят предложената система като гъвкава и надеждна.
Бъдещата работа по контролера е насочена основно върху хардуера, което включва допълнителни модули и осъществяване на връзката им с развойната среда. Предвижда се и добавяне на комуникационен интерфейс за работа в мрежа.

ЛИТЕРАТУРА

### [1] Hugh Jack, Automating Manufacturing Systems with PLCs, http://clay-more.engineer.gvsu.edu/~jackh/books.html [2] Data Sheet, ATmega16/ATmega32, ATMEL

За контакти:
Симеон С. Иванов, студент специалност “Електроника”, 2 курс, Русенски

### университет “Ангел Кънчев”, e-mail: the_day_of_doom@abv.bg

гл. ас. д-р инж. Анелия Владимирова Манукова, кат. “Електроника”, Русенски

### университет “Ангел Кънчев”, тел.: 082 888 366, е-mail: amanukova@ecs.ru.acad.bg

Рецензент:

Фиг.4. Диалогов прозорец на развойната среда.

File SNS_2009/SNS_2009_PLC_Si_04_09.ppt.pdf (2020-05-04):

## СТУДЕНТСКА НАУЧНА КОНФЕРЕНЦИЯ НА РУСЕНСКИ УНИВЕРСИТЕТ „АНГЕЛ КЪНЧЕВ”

2009 г.

## Програмируем контролер AVR–LPC

кат. Електроника при РУ “Ан.Кънчев”

автор: Симеон Иванов

научен ръководител: гл. ас. д-р инж. Анелия Манукова

# ЦЕЛ

Презентацията представя проект “AVR-PLC”,

## изграждащ PLC контролер включващ крайно устройство с интегриран потребителски интерфейс (UI) и ядро (kernel), грижещо се за

изпълнение на ladder diagram.

## Представена е развойна среда, ускоряваща процеса на разработване и тестване на потребителските

програми.

# Структурна схема на AVR–LPC

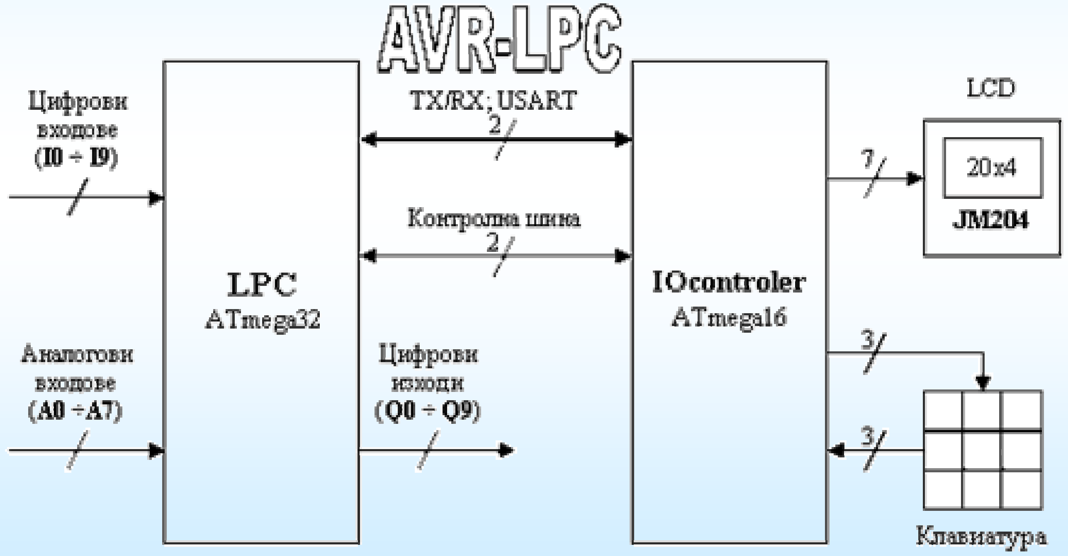
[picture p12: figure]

# Алгоритъм на работа на главния контролер AVR–LPC

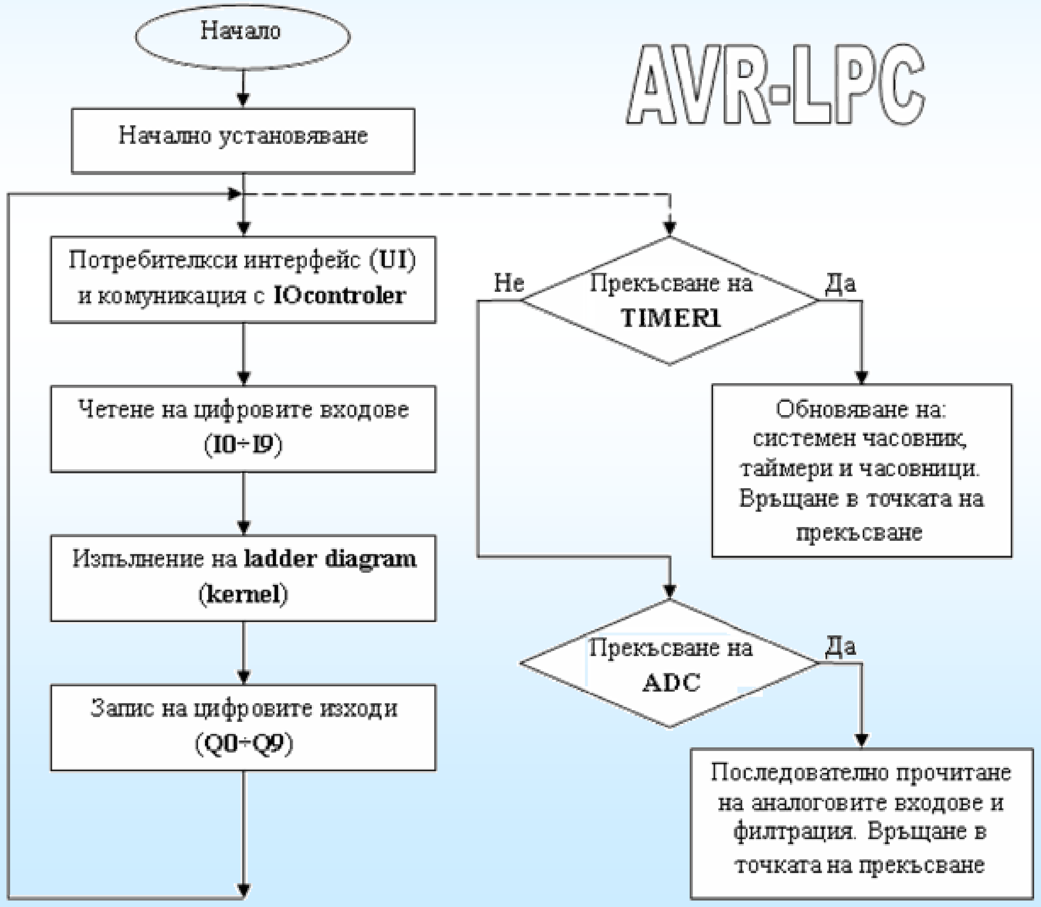
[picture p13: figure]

## Алгоритъм на работа на входно -изходния контролер на AVR–LPC

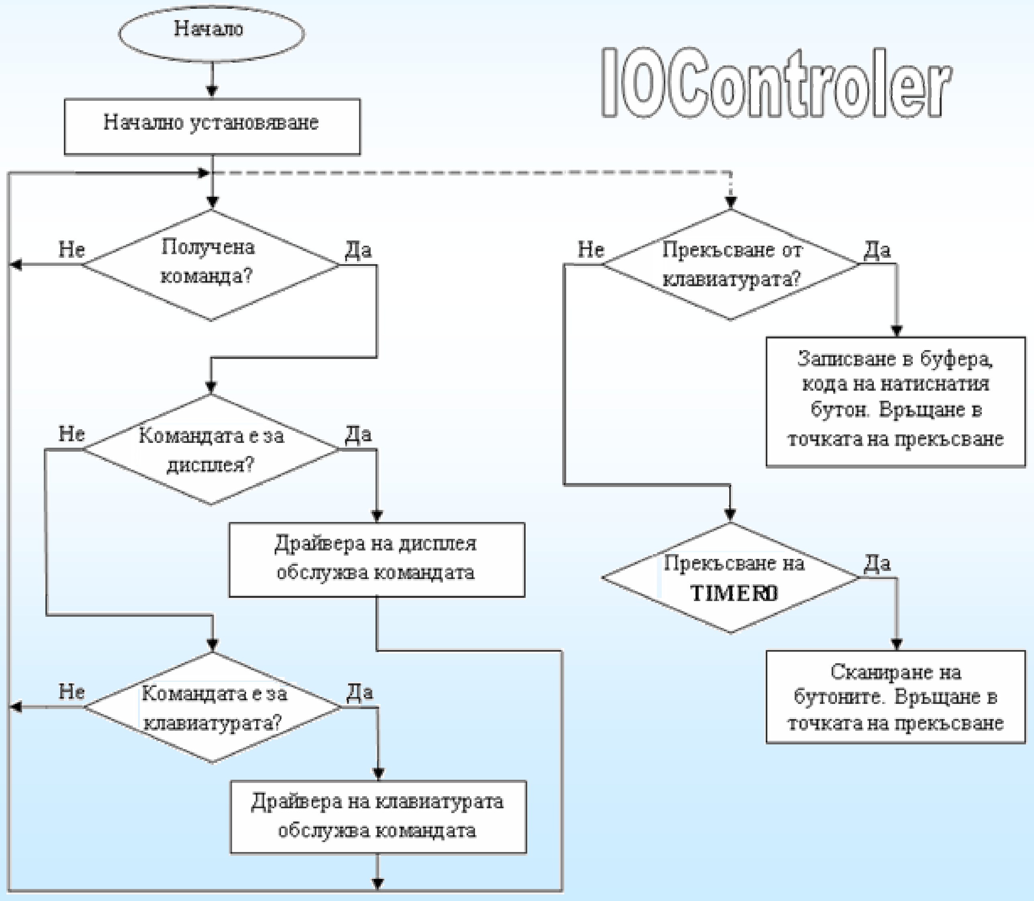
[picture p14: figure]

## Резултати

## Технически параметри на програмируемия контролер AVR–LPC

- 10-bit ADC; - честота на дискретизация: 125KHz; - софтуерен филтър; аналогови входове (A0÷A7; мултиплицирани) | - минимално време за реакция: 10ms; - гарантирано време за реакция: >20ms; цифрови изходи (Q0÷Q9) | - минимално време за реакция: 10ms; - гарантирано време за реакция: >20ms; цифрови входове (I0÷I9)

Хардуерни параметри

- минимален период: 10ms; - гарантиран период: >20ms; - максиален период: 65,535s; - три режима на работа:
мултивибратор, | таймер | със
закъснение на включването (ON delay timer), таймер със закъснение на
изключването (OFF delay timer);

таймери

- 24 часов период; - час на включване/ изключване; часовници | - произволен формат на запис; - автоматично разпознаване на въвеждания обект; ladder diagram: 16x12 символа

Софтуерни параметри

## Резултати

## Технически параметри на програмируемия контролер AVR–LPC

RS тригери

маркери | - избор посоката на броене (чрез контактна инструкция) - типа на сравнение: <; =; >; - максимална стойност: 65535; - възможност за автоматично нулиране на брояча; - минимално време за реакция: 10ms.; - гарантиранo време за реакция: >20ms; броячи | - софтуерно избиране стойността на опорно напрежение; - тип на сравнение: <; =; >; - избор на аналогов вход; аналогови компаратори

## Резултати

## Технически параметри на програмируемия контролер AVR–LPC

## Диалогов прозорец на развойната среда

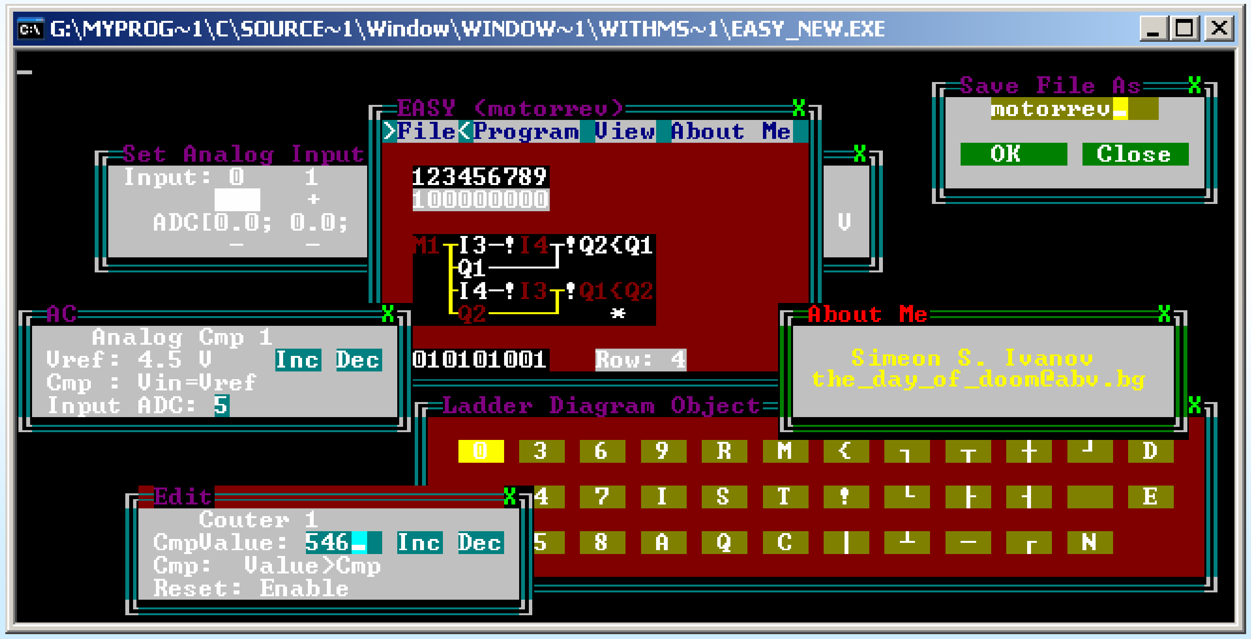
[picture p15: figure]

## ИЗВОДИ

| Разработени са програмируем логически контролер AVR- LPC, изпълняващ ladder diagram, и съпъстващата го развойна среда.
| В DOS среда, потребителя разполага с файлова система, позволяваща съхраненение, зареждане, изпълнение на произволна програма. Това определя и по-високата продуктивност на предложената система.
| Проведените тестове на прототипа и развойната среда на контролера доказват работоспособността му и определят предложената система като гъвкава и надеждна.

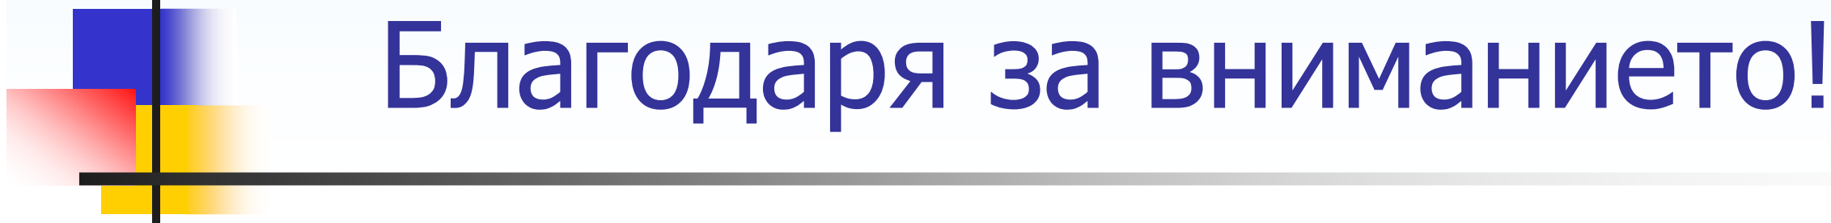
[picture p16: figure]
Благодаря за вниманието!

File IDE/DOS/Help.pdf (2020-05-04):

ИНСТАЛИРАНЕ И КОНФИГУРИРАНЕ

Развойната среда на AVR-LPC (LD.exe) е DOS приложение което може да работи и в среда на емулация в Windows среда. За да може да се използва пълноцено е необходимо да се изпълнят следните правила:

1) Стартиране на развойната среда от файла IDE.exe – конзолна Windows програма иницялизираща драйвера за достъп до входно/ изходните портове, след което подава управлението на LD.exe.
2) Работа на цял екран – режим стартиращ по подразбиране. Необходима е за коректната комуникация между развойната среда и програмирания PLC контролер. За излизане/влизане от него се използва се използва клавишната комбинация ALT+ENTER.
3) Инсталиране на DLPORTIO (драйвер за директен достъп до портовете под Windows NT и производните му).
4) Потребителските програми се съхраняват в работната директория на развойната среда. Желателно е тя да е в корена на диска. Например “C:\LDIDE\” или още по-добре да се ползва диск различен от системния.

При стартиране на IDE.exe, се минава в режим на цял екран. На фиг.1 е показан главния прозорец на редактора.

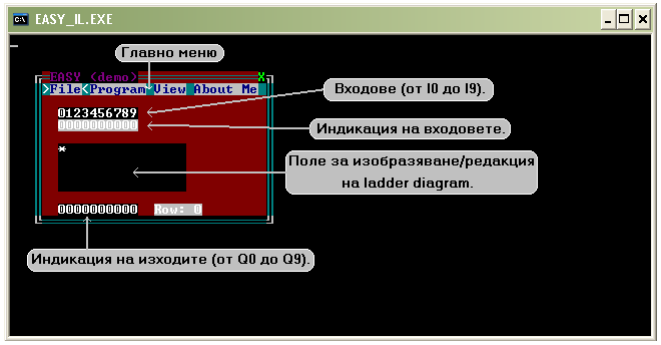
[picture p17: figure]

Фиг.1. Главен прозорец на EASY_IL (IDE)

Съдържа главно меню, бутони (от 0 до 9) имитиращи входовете, непосредствено под тях е съответната им индикация (логическа 0 или 1). Следва полето на LD, а накрая е индикация на изходите.

ГЛАВНО МЕНЮ

Състои се от четири елемента, първите три със съответните им PopUp менюта:

1) File – Предоставя възможност за създаване (New), отваряне (Open), съхранение текущите промени (Save) и запaзване във създаден от потребителя файл (Save as) на Ladder Diagram. Съдържа и полето Exit заизход от редактора. Трябва да се направят три важни уточнения:

а) Избирането на New не съхранява текущата диаграма;

б) При създаване на нова диграма, за да работи Save е необходимо предварително чрез Save as да се зададе име на файла;

в) При избор на Exit се излиза от редактора без съхраняване на последно направените промени;

2) Program – Служи за управление на текущата програма::

а) Compile генерира от текущата ladder diagram файл с разширение *.IL, съдържащ псевдоасмблерни инструкции описващи диаграмата;

б) Run – за разрешаване симулацията на LD;

в) Stop – спира симулацията на LD, запазват се текущите стойности на маркерите, броячите и д.р. обекти на диаграмата;

г) Reset – нулира състоянията и настройките на обектите на LD;

д) Convert – при зареждане на програмен файл от стария формат, се налага конвертиране в текущия. Напрактика опция ползвана само в процеса на разработка.

3) View – за извеждане на два основни прозореца:

а) LD Object – показва и позволява въвеждането на всички символи подържани от LD. Използва се за редакция на диаграмата, навигацията в нея се извършва чрез стрелките (фокуса остава на главния прозорец).;

б) Analog Input – за въвеждане стоийности на аналоговите входове на контролера;

4) About Me – извежда прозорец съсдържащ информация за автора.

Редакция на ladder diagram

За редакция на диаграмата има два основни варианта: чрез прозореца LD Object или от клавиатурата. Втория вариянт позволява вмъкване на специални символи чрез клавишите или ендократно натискане на Enter старртира режим въвеждане на символ (избира се чрез стрелките). Ще бъда разгледани двата варианта.

### РЕДАКЦИЯ ЧРЕЗ „LD Object”

От главното меню се избира View->LD Object. Работния плот придобива следния вид (фиг.2):

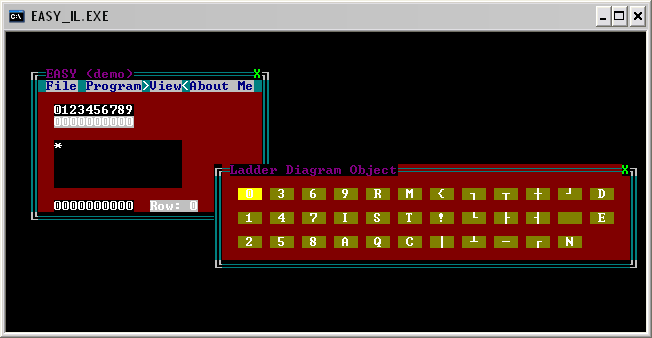
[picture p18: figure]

Избора на елемент става чрез клавиша Tab или мишката, а вмъкването чрез Enter. Стрелките на клавиатурата служат за навигация в полето за редакция на ladder diagram. Чрез SPACE се трие въведения символ.

### РЕДАКЦИЯ ЧРЕЗ КЛАВИАТУРАТА

При редактиране на LD чрез клавиатурата в сила са следните съотвествия между символите изграждащи обектите на ladder diagram и клавишите (таблица 1):

### Таблица 1

### Редакция на ladder diagram чрез “бързите” клавиши

Enter | Режим въвеждане на символ/ Потвърждение на въвеждането.
Space | Изтрива символа маркиран от курсора (звездичка).

Стрелки (наляво, надясно, нагоре, надоло) | За навигация в полето на LD; Избор на елемент в режим на редакция (Enter).
‘-‘ (минус) | ─
‘|’ | │
‘F’ | ┌
‘K’ | ┐
‘G’ | ┴
‘U’ | ┬
‘О’ | ┤
‘V’ | ├
‘B’ | ┘
‘L’ | └
‘X’ | ┼
‘I’, ‘Q’, ‘A’, ‘N’, ‘M’, ‘R’, ‘S’, ‘T’, ‘C’, ‘E’, ‘D’, ‘{‘, ‘0’..’9’, ‘!’ | Съответните им символи.

ВХОДОВЕ
Контролера разполага с десет входа, от I0 до I9. Инвертирането на вход става чрез символа ‘!’.

ИЗХОДИ
Контролера разполага с десет изхода, от Q0 до Q9. Изхода може да се ползва като контактна инструкция или релеен. Когато се използва като контакт инвертирането му става чрез символа ‘!’.

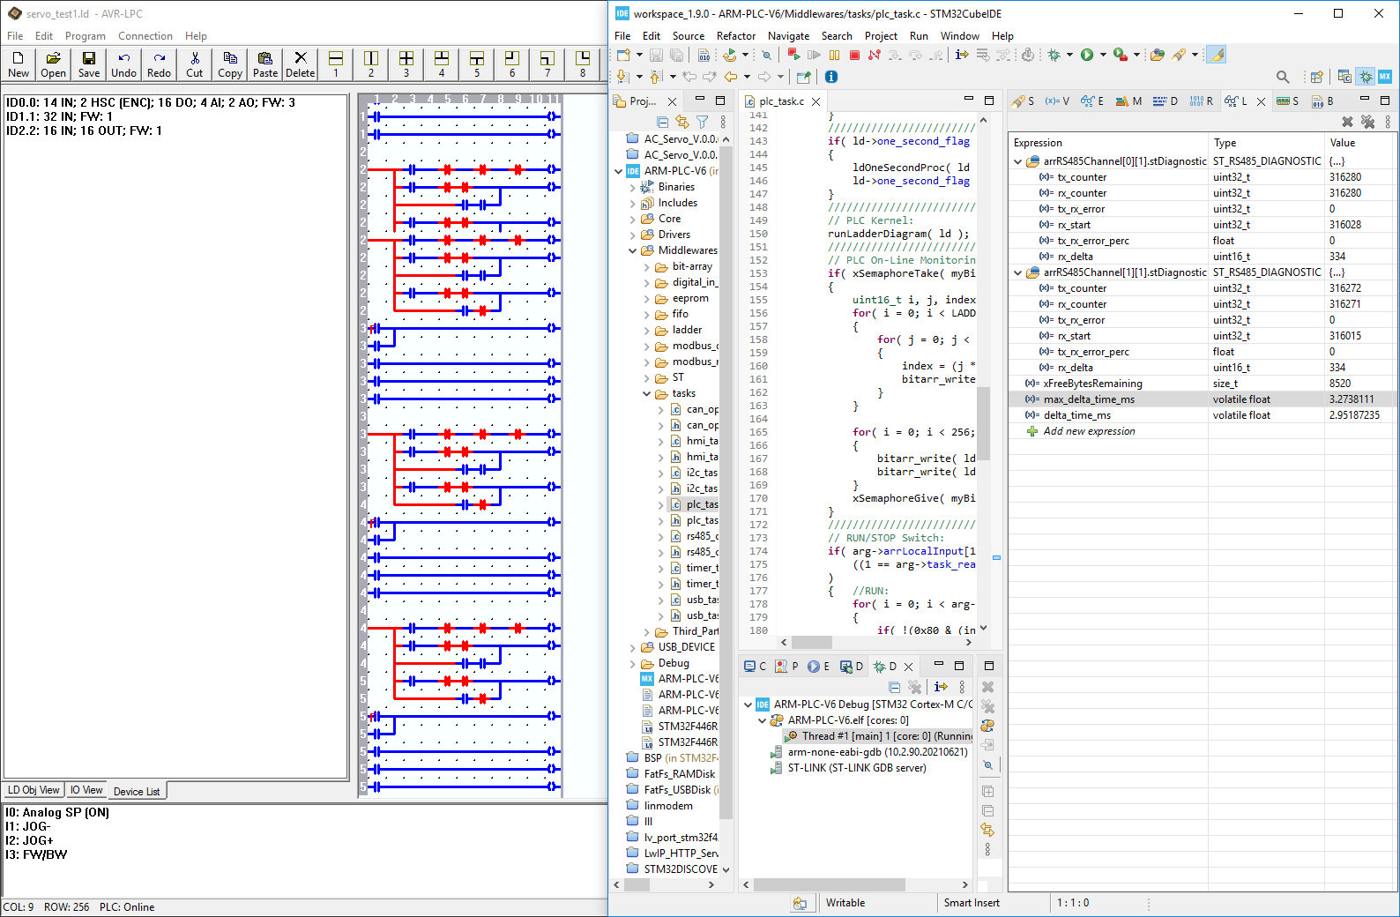
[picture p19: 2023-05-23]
IDE/Windows/v6/ARM_PLC_IDE_V6_8.png

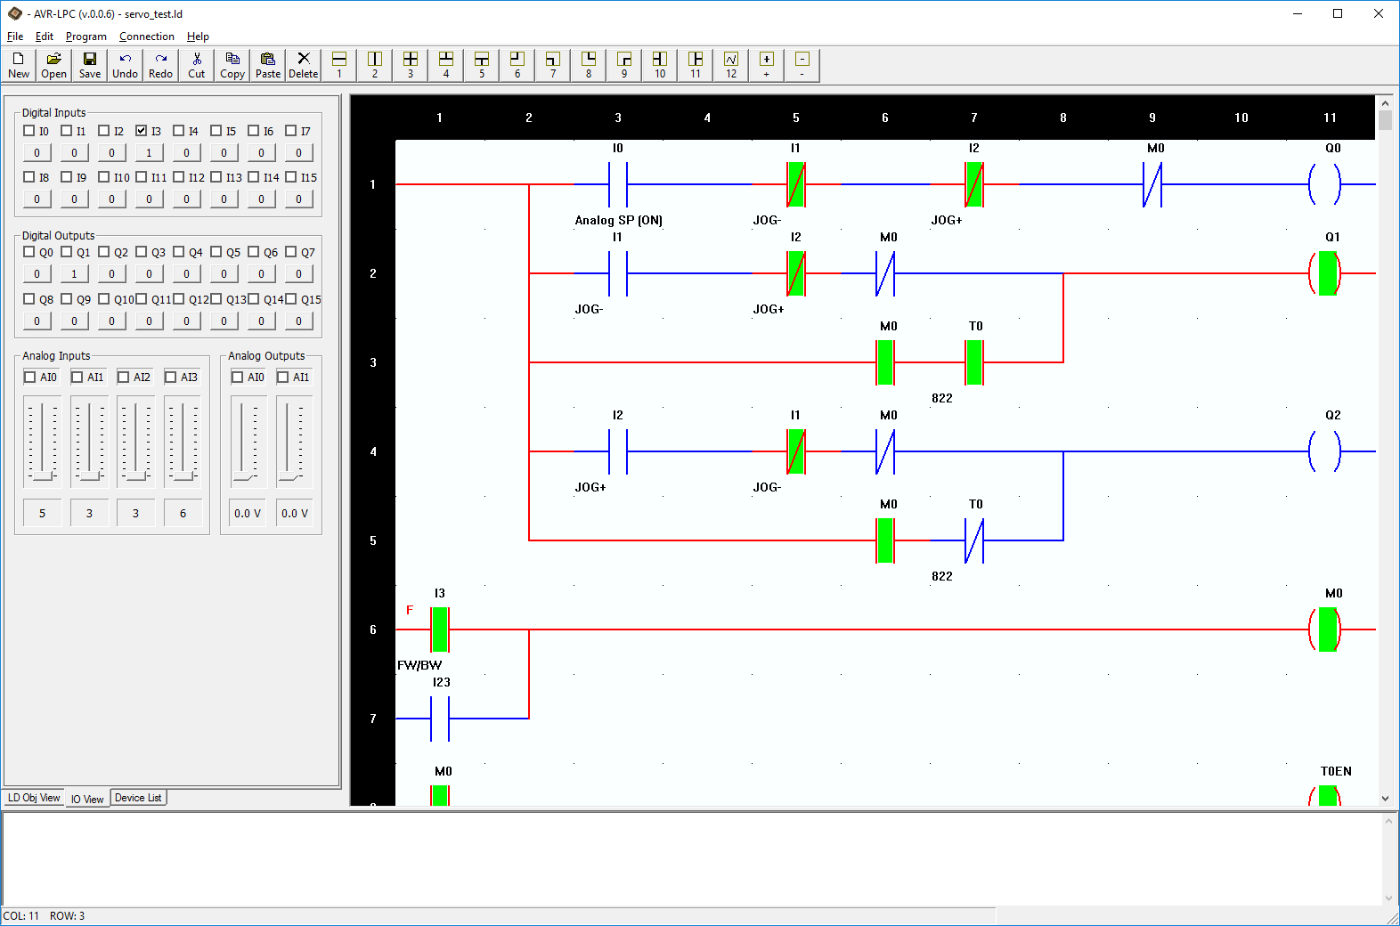
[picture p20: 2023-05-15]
IDE/Windows/v6/ARM_PLC_IDE_V6_6.png

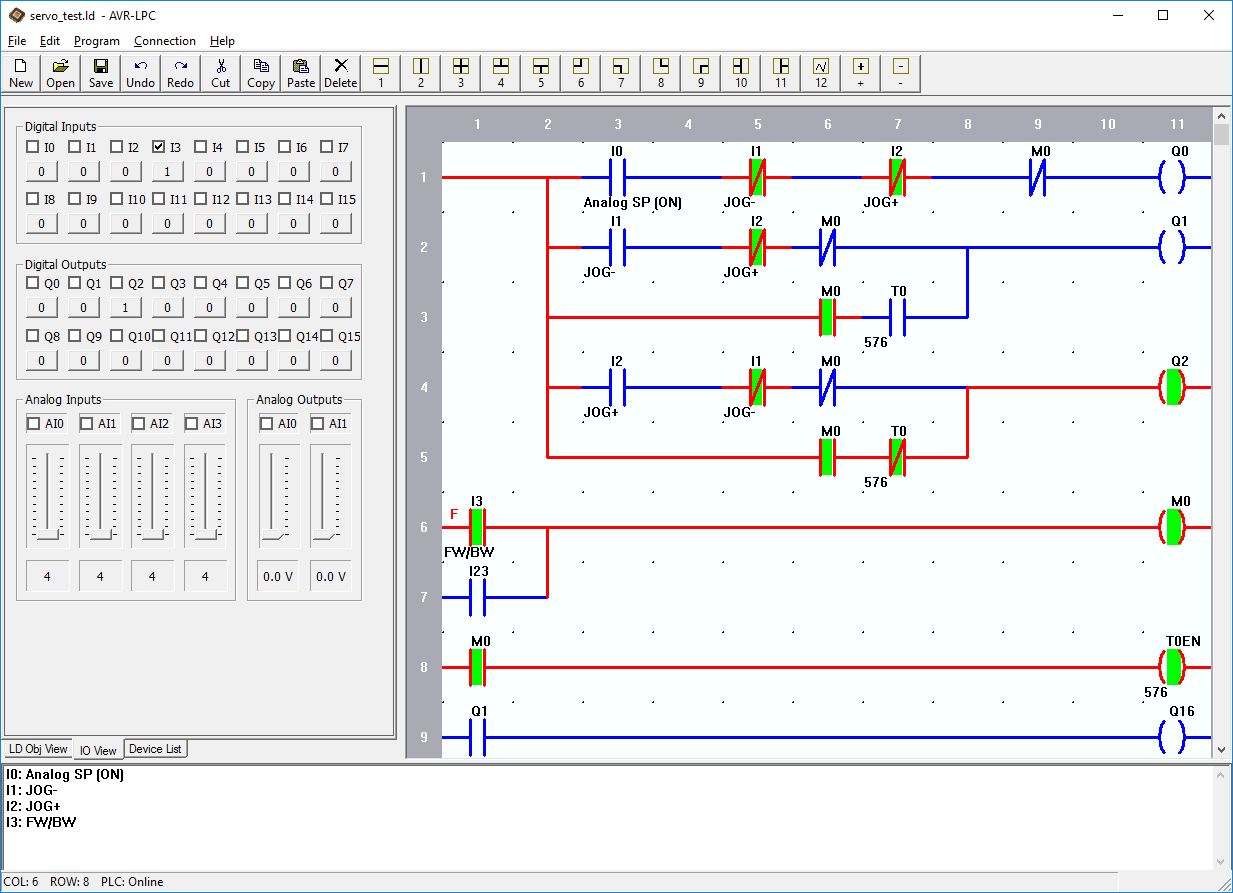
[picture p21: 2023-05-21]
IDE/Windows/v6/ARM_PLC_IDE_V6_7.png

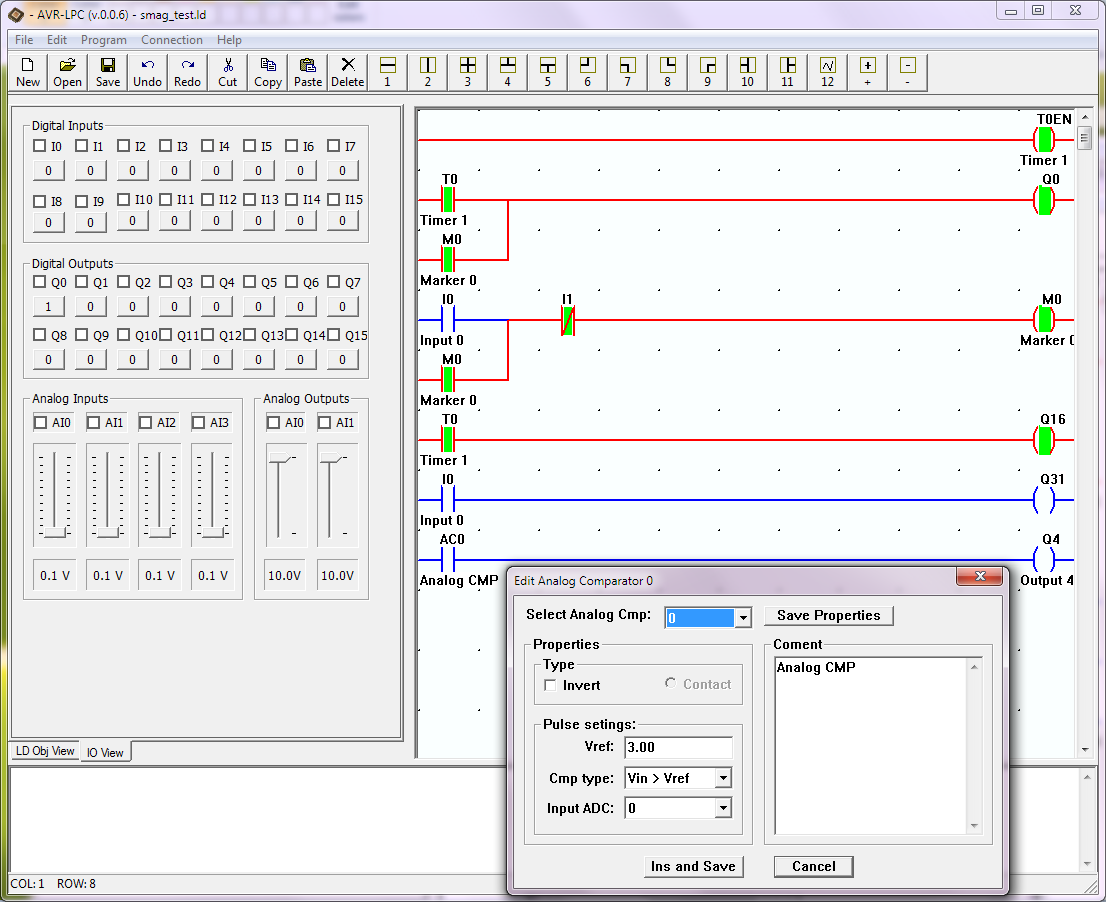
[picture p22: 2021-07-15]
IDE/Windows/v6/ARM_PLC_IDE_V6_4.png

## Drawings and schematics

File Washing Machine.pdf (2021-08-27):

1

## РУ “АНГЕЛ КЪНЧЕВ”

Факултет: “ЕЕА”
Катедра: “АИУТ”

### Курсова работа По Промишлени контролери

На: Симеон С. Иванов
Факултетен номер: Ø93665
Група: 5
Специалност: Електроника
Дата: | | Приел: | Предал: |

2

В настоящата курсова работа ще се разгледа примерно проектиране на пералня с микропроцесорен управляващ модул. Целта на задачата е да се усвой практическото приложение на системите с вграден микроконтролер чрез практическа задача. Още в началото ще направя уточнението, че сърцето на проекта е микропроцесорен модул “AVR-LPC v.0.0.5”, разработен от автора, ползван базово като PLC.

Най-необходимите елементи за базово управление на пералня са главно задвижване, терморегулатор и система за снабдяване с вода.
Таблично представени представляват:

Базов хардуер към микропроцесорния модул AVR-LPC
Тип на модула/ използван ресурс на контролера | Изпълнителен механизъм / сензор | Управляващо устроийство / първичен преобразувател | Необходими входове към микропроцесора | Необходими изходи от микропроцесора
Задвижване | Асинхронен мотор, 3-фазен | Честотен инвертор | “Ready”, готовност за работа (цифров) | Аналогов, задание за скорост

“ON” въртене на
мотора
“F/R” избор на
посока
Терморегулатор | Аналогов сензор | Преобразувател температура->напрежение, обратна връзка към процесора | Аналогов вход | НЕ
| Силов модул (ШИМ) | Управление чрез аналогово задание от контролера | Цифров сигнал “Ready” | Цифров сигнал “ON”

Аналогов изход
Аналогово задание за температура, потенциметър | Към контролера | Аналогов вход | НЕ
Водоснабдителн а система | Датчик за ниво | Използва се пресостатат даващ директно цифров сигнал. | Два цифрови входа, за максимално и минимално ниво | НЕ
| Помпа, за източване на водата | Контактор/ подходящо реле | Един, отпаднала защита на помпата | Един цифров изход
| Магнет вентили за пълнене/източ ване на водата | Контролера | НЕ | Два цифрови изхода
Спомагателни | Магнет вентили за управление дозирането на перилните препарати | Контролера | НЕ | Три цифрови изхода

3

Избрания микропроцесорен модул разполага с:

Памет: FLASH (128KB); EEPROM (2KB); SRAM (8KB), BOOT (8KB)

### 10 оптоизолирани цифрови входа, 24VDC 12 оптоизолирани цифрови изхода, 24VDC/500ma/канал 7 аналогови входа (хардуерно се определя дали входа е напреженов

или токов; 0-10V или 0-25ma).

### 2 аналогови изхода; 0-10V

RS485 галлванично изолиран, за комуникация (например ModBUS). RS232 галванично изолиран, опционално се замества с USB към виртуален сериен порт (галванично развързан).

Вградени в самия модул са също и RTC с външна батерия, I²
C
EEPROM и DIP Switch използван при избор адреса на устройството в мрежа.

Освен това микропроцесорния модул разполага с графичен дисплей 122х32 пиксела с подсветка, позволяващ използването на произволна кодова таблица (мултиезичност).

Разбира се след дисплея няма как да се пропусне и матричната клавиатура от 3x3 (4х4) символа. Опционално, ако не се ползва дисплея/клавиатурата се освобождава I²
C, SPI, USART и/или няколко свободни изхода с цел разширяване на базовата функционалност.

Вижда се, че предложения модул напълно покрива изискванията към управлението на пералнята. Честотния преобразувател и силовия ШИМ на нагревателя представляват готови модули.

Захранващия модул е изпълнен като изпулсен с изходни напрежения от 24VDC/5A и 15VDC/500mA. Неговия подробен анализ не приоритетен в текущата задача. За аналоговата част са необходими и два линейни стабилизатора (5 и 12VDC).

За термодатчик е избран TC1047A, аналогов изход с напрежение от 500mV-1500mV в диапазона от 0° до 100°C. За да се преобразува в сигнал от 0 до 10V за аналоговия вход на контролера се използва сумиращ усилвател изваждащ 500mV от изхода на сензора. Следва усилване на сигнала 10 пъти, мащабиращо входния сигнал към пълния обхват на аналоговия вход.
Условно в схемата изпълнителните механизми са отбелязани като магнет вентили. Разбира се те биха били подбрани според конкретната механична конструкция

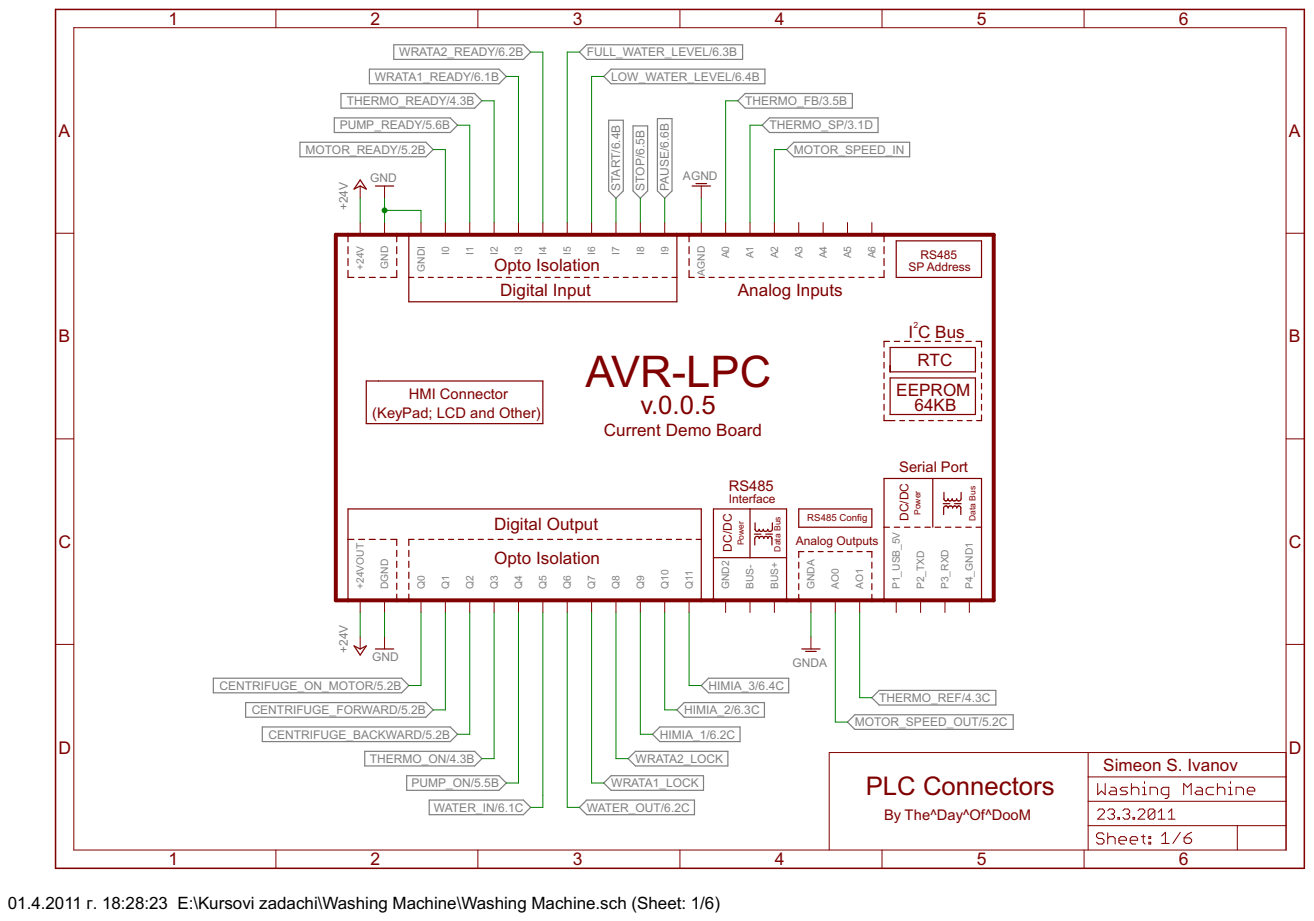
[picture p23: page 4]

HMI Connector
(KeyPad; LCD and Other)

+24VOUT DGND Q0 Q1 Q2 Q3 Q4 Q5 Q6 Q7 Q8 Q9 Q10 Q11 GND2 BUS- BUS+ GNDA

By The^Day^Of^DooM

01.4.2011 г. 18:28:23 E:\Kursovi zadachi\Washing Machine\Washing Machine.sch (Sheet: 1/6)

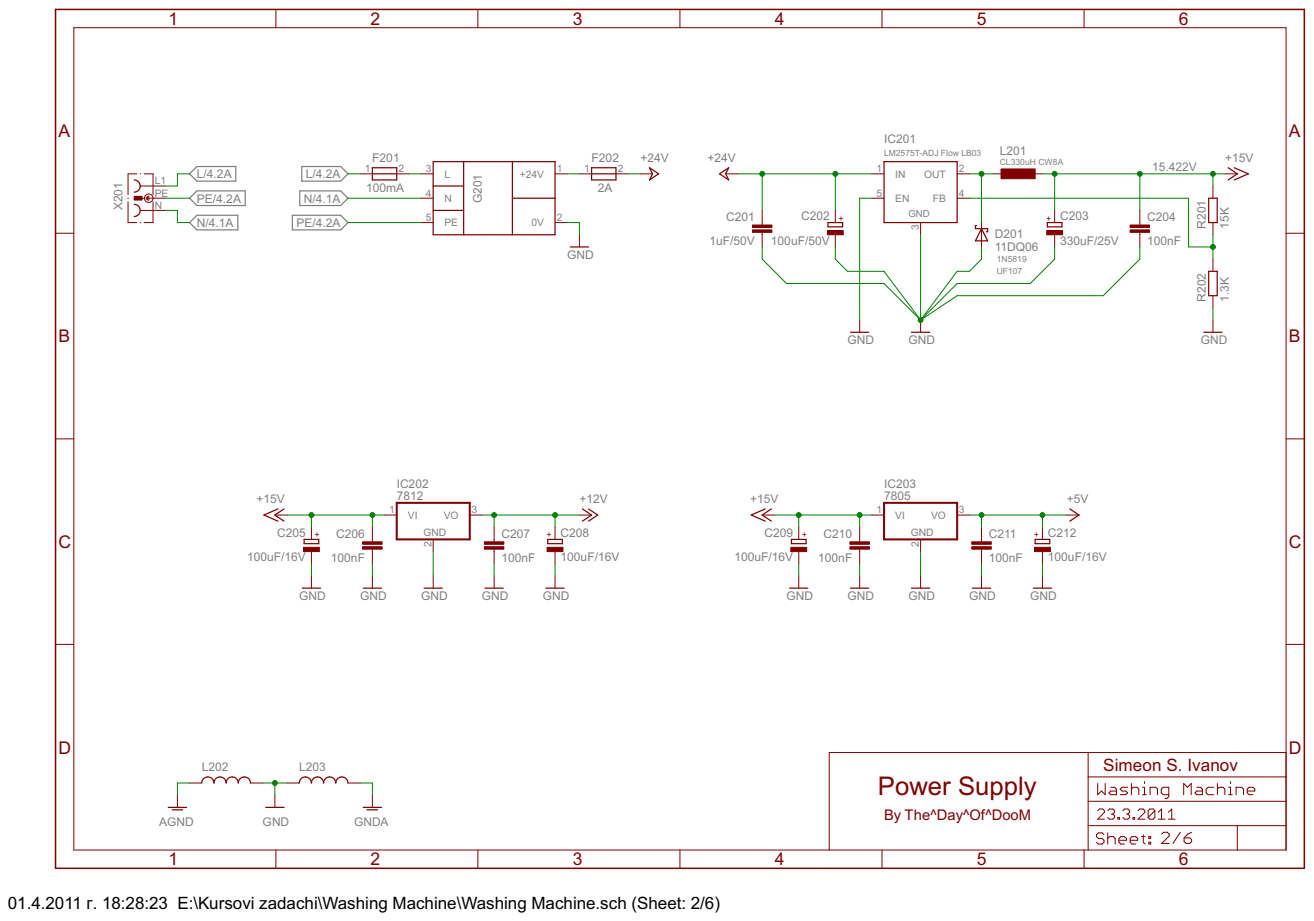
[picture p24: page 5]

By The^Day^Of^DooM

01.4.2011 г. 18:28:23 E:\Kursovi zadachi\Washing Machine\Washing Machine.sch (Sheet: 2/6)

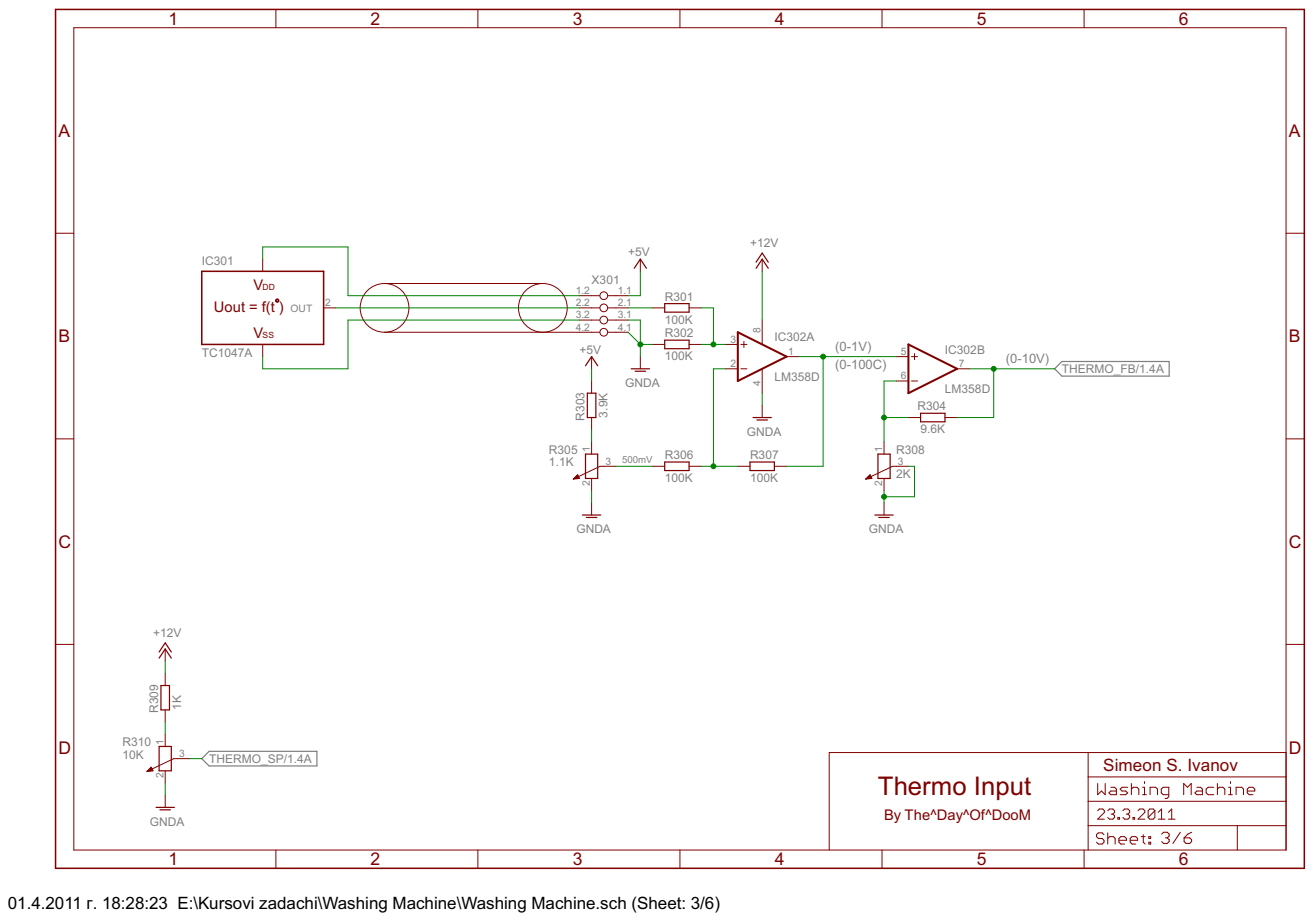
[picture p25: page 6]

By The^Day^Of^DooM

01.4.2011 г. 18:28:23 E:\Kursovi zadachi\Washing Machine\Washing Machine.sch (Sheet: 3/6)
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

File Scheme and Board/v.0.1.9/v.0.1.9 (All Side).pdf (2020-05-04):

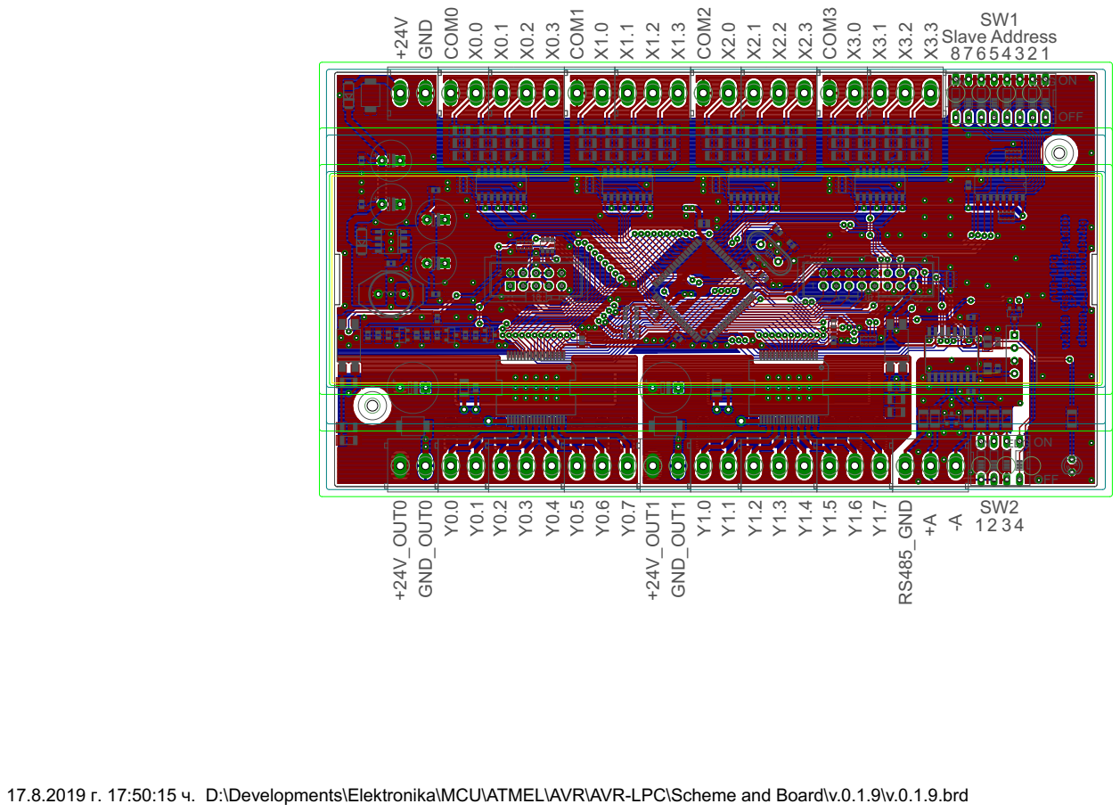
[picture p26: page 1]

17.8.2019 г. 17:50:15 ч. D:\Developments\Elektronika\MCU\ATMEL\AVR\AVR-LPC\Scheme and Board\v.0.1.9\v.0.1.9.brd

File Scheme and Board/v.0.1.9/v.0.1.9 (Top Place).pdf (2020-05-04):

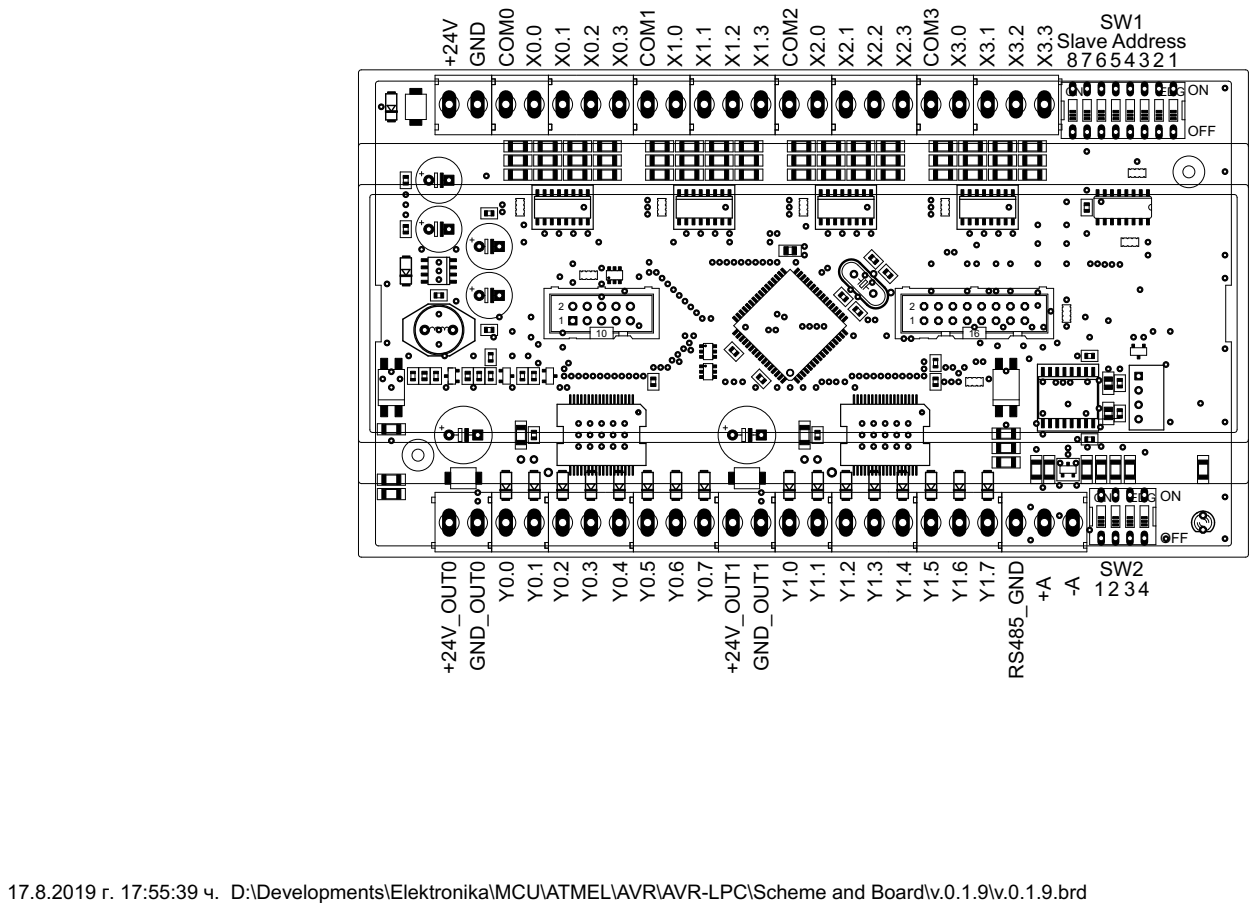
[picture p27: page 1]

17.8.2019 г. 17:55:39 ч. D:\Developments\Elektronika\MCU\ATMEL\AVR\AVR-LPC\Scheme and Board\v.0.1.9\v.0.1.9.brd

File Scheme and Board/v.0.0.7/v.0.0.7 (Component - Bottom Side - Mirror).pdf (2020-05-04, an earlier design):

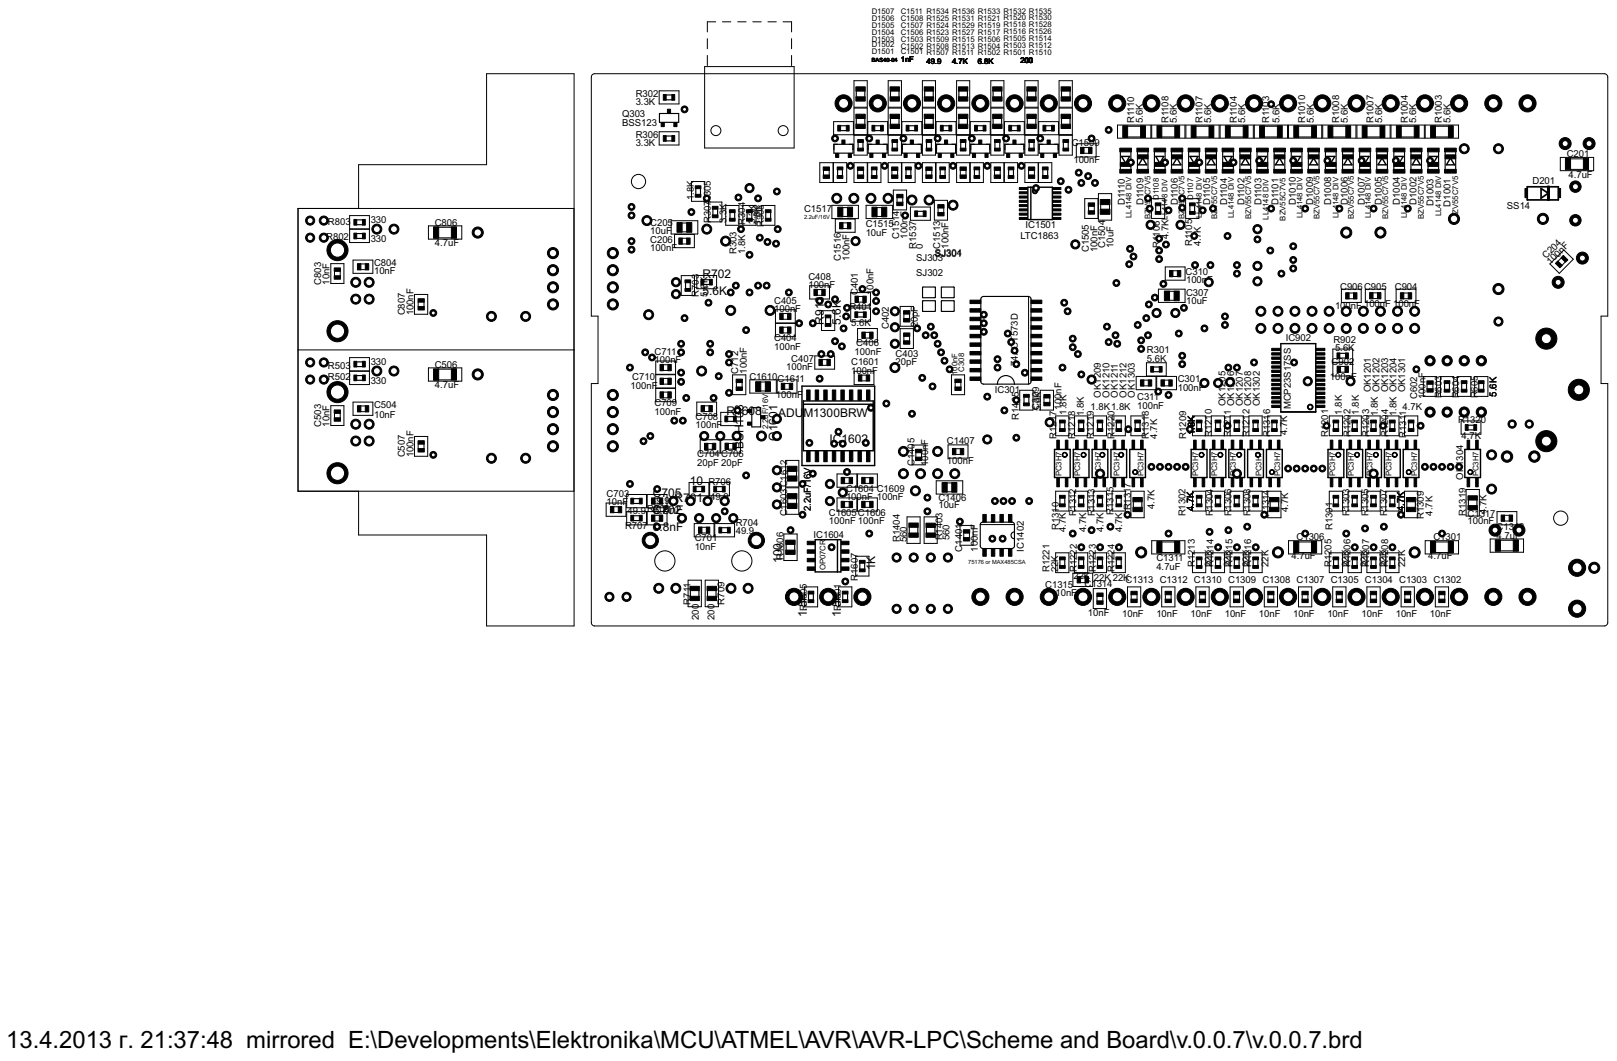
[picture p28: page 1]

49.9

13.4.2013 г. 21:37:48 mirrored E:\Developments\Elektronika\MCU\ATMEL\AVR\AVR-LPC\Scheme and Board\v.0.0.7\v.0.0.7.brd

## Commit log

2021-05-24 Fix SELECT/COPY/CUT/PASTE and DELETE
2023-05-15 Remove Ld Edit Frame
2023-10-26 Undo/Redo: first test with wire object
2024-06-10 Draw LD in timer
